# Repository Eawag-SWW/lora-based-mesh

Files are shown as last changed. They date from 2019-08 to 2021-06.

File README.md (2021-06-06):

# LPWAN for sewer monitoring - A synchronous LoRa-based mesh data communication protocol
Documentation, firmware and hardware specification | Cooperative development: InES, ZHAW Winterthur & Eawag, Dübendorf (Switzerland) 

## Graphical Abstract

EBI_etal_graphical_abstract_xs

## Synopsis
Although emerging low-power wireless communication techniques allow efficient data transfers with great above-ground performance, for underground or indoor applications a large coverage range is difficult to achieve due to physical and topological limitations. This repository provides detailed information on a novel LPWAN concept that i) enhances transmission reliability, efficiency and flexibility in range-critical situations through meshed multi-hop routing, and ii) ensures a precise time-synchronization through optional GPS or DCF77 long-wave time signaling.

## Project-related Open Access Publication
https://ieeexplore.ieee.org/document/8703036

## Hardware Specification
Find i) the assembly of the material used, ii) the drawings for sensor node chassis, and iii) PCB related material [here](./Hardware).
## Software Code
Concept-specific firmware is provided [here](./Software).
## Miscellaneous
Institutional project website -> www.eawag.ch/sewerlpwan

Related project(s): 
Urban Water Observatory -> www.eawag.ch/uwo

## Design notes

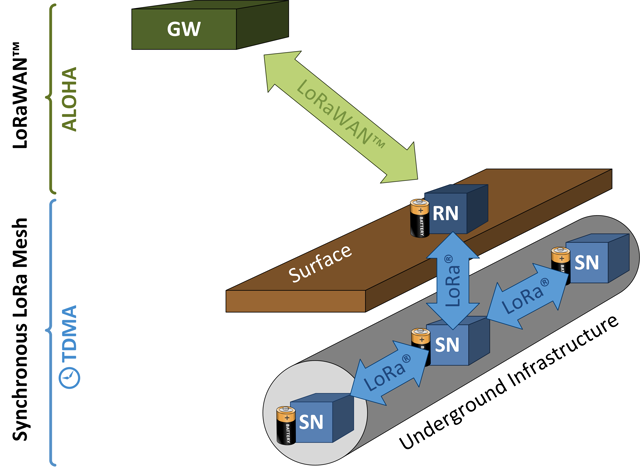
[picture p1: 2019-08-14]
EBI_etal_graphical_abstract_s.png

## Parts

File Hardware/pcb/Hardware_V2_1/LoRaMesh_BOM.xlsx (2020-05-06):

Designator | Comment | Description | Footprint | LibRef | Quantity | Manufacturer | Manufacturer Part Number | Distributor | Distributor Part Number | Value
A2, A3 | Ant Chip |  | ANT_CHIP_868_woC | Ant_Chip_868_woC | 2 |  |  | Digikey | 931-1082-2-ND | ILA.02
C1, C2, C58, C59, C60, C76, C80, C81 | 100uF | Capacitor SMD | rlc_805_smd | Cap | 8 |  |  |  |  | 100uF
C3, C4, C5, C6, C14, C15, C21, C23, C24, C28, C42, C57, C67, C71, C72, C73, C78, C79, C82 | 100nF | Capacitor SMD | rlc_402_smd | Cap | 19 |  |  |  |  | 100nF
C7, C8, C18, C19, C20, C26, C36, C38, C39 | 47pF | Capacitor SMD | rlc_402_smd | Cap | 9 |  |  |  |  | 47pF
C9 | 33pF | Capacitor SMD | rlc_402_smd | Cap | 1 |  |  |  |  | 33pF
C10 | 1.5pF | Capacitor SMD | rlc_402_smd | Cap | 1 |  |  |  |  | 1.5pF
C11, C29, C50 | 4.7pF | Capacitor SMD | rlc_402_smd | Cap | 3 |  |  |  |  | 4.7pF
C12 | 1.2pF | Capacitor SMD | rlc_402_smd | Cap | 1 |  |  |  |  | 1.2pF
C13 | 1.8pF | Capacitor SMD | rlc_402_smd | Cap | 1 |  |  |  |  | 1.8pF
C16, C33, C34, C37, C40, C41, C46, C47, C51, C83, C101, R15, R46 | NC | Capacitor SMD, Capacitor SMD, Capacitor SMD, Capacitor SMD, Capacitor SMD, Capacitor SMD, Capacitor SMD, Capacitor SMD, Capacitor, Capacitor SMD, Capacitor, Resistor SMD - IEC symbol version, Resistor SMD - IEC symbol version | rlc_402_smd | Cap, Cap, Cap, Cap, Cap, Cap, Cap, Cap, C, Cap, C, Resistor, Resistor | 13 |  |  |  |  | NC
C17 | 3.3pF | Capacitor SMD | rlc_402_smd | Cap | 1 |  |  |  |  | 3.3pF
C22, C25, C43, C45 | 1nF | Capacitor SMD | rlc_402_smd | Cap | 4 |  |  |  |  | 1nF
C27, C44, C56, C66, C70, C75 | 1uF | Capacitor SMD | rlc_402_smd | Cap | 6 |  |  |  |  | 1uF
C30, C32 | 6.8pF | Capacitor SMD | rlc_402_smd | Cap | 2 |  |  |  |  | 6.8pF
C31 | 2.7pF | Capacitor SMD | rlc_402_smd | Cap | 1 |  |  |  |  | 2.7pF
C35 | 10nF | Capacitor SMD | rlc_402_smd | Cap | 1 |  |  |  |  | 10nF
C48, C49, C87, C88 | 15pF | Capacitor SMD | rlc_402_smd | Cap | 4 |  |  |  |  | 15pF
C52, C53, C54, C74, C98, C99, C100 | 10uF | Capacitor SMD | rlc_603_smd | Cap | 7 |  |  |  |  | 10uF
C68, C69 | 18pF | Capacitor SMD | rlc_402_smd | Cap | 2 |  |  |  |  | 18pF
C77 | NC | Capacitor SMD | rlc_603_smd | Cap | 1 |  |  |  |  | NC
D1 | BAT60JFILM | BAT60JFILM | SOD323/A | BAT60JFILM | 1 | STMicroelectronics | BAT60JFILM | Digikey | 497-3707-1-ND | BAT60JFILM
D2 | LED_ORANGE | LED ORANGE CLEAR 0603 SMD | CD1608-0603 | LED_ORANGE | 1 | Lite-On Inc. | LTST-C191KFKT | digikey |  | LTST-C191KFKT
D3 | LED_GREEN | LED GREEN CLEAR 0603 SMD | CD1608-0603 | LED_GREEN | 1 | Lite-On Inc. | LTST-C191KGKT | digikey |  | LTST-C191KGKT
J1, J2, J4 | 0R | Switching Path between two different with a Resistor | 0402 3-Way | 3 Way Resistor Switch | 3 |  |  |  |  | 0R
J10 | DM3AT-SF-PEJM5 | DM3 Series 8 Position Right Angle SMT Push Push Ejection MicroSD Card Connector | DM3AT-SF-PEJM5_DM3AT-SF-PEJM5(Primary) | DM3AT-SF-PEJM5 | 1 | Hirose Electric Co Ltd | DM3AT-SF-PEJM5 | Digikey | HR1964TR-ND | DM3AT-SF-PEJM5
JP1 | Jumper 3-Pol | Jumper 3 Pol | JMP 1X3 | Jumper 3-Pol | 1
JP2 | Jumper | Jumper Wire | bridge_254mm | Jumper | 1 |  |  |  |  | NC
L1 | 82nH | Inductor SMD | rlc_402_smd | Inductor | 1 | Murata | LQG15HS82NJ02D | Digikey | 490-2634-1-ND | 82nH
L2 | 33nH | Inductor SMD | rlc_402_smd | Inductor | 1 | Murata | LQW15AN33NJ00D | Digikey | 490-1152-1-ND | 33nH
L3, L20 | 2.2u | Inductor | rlc_1008_smd | Inductor | 2 | Murata | DFE252012P-2R2M=P2 | Digikey | 490-10649-1-ND | 2.2u
L4, L7 | 10nH | Inductor SMD | rlc_402_smd | Inductor | 2 | Murata | LQG15HS10NJ02D | Digikey | 490-2623-1-ND | 10nH
L5 | 6.2nH | Inductor SMD | rlc_402_smd | Inductor | 1 | Murata | LQG15HS6N2S02D | Digikey | 490-2620-1-ND | 6.2nH
L6 | 15nH | Inductor SMD | rlc_402_smd | Inductor | 1 | Murata | LQG15HS15NJ02D | Digikey | 490-2625-1-ND | 15nH
L8, L10, L11, L14, R16, R40, R45, R47, R66, R67, R68, R69 | 0R | Inductor SMD, Inductor SMD, Inductor SMD, Inductor SMD, Resistor SMD - IEC symbol version, Resistor SMD - IEC symbol version, Resistor SMD - IEC symbol version, Resistor SMD - IEC symbol version, Resistor SMD - IEC symbol version, Resistor SMD - IEC symbol version, Resistor SMD - IEC symbol version, Resistor SMD - IEC symbol version | rlc_402_smd | Inductor, Inductor, Inductor, Inductor, Resistor, Resistor, Resistor, Resistor, Resistor, Resistor, Resistor, Resistor | 12 |  |  |  |  | 0R
L9 | 12nH | Inductor SMD | rlc_402_smd | Inductor | 1 | Murata | LQG15HS12NJ02D | Digikey | 490-2624-1-ND | 12nH
L12, L16 | (L) LPS3015 | Coilcraft LPS3015 3mm x 3mm | LPS3015 L 3 x 3 | (L) LPS3015 | 2 | Coilcraft | LPS3015-152MRB | Mouser | 994-LPS3015-152MRB | 1.5uH 1.7A 20%
L13 | 18nH | Inductor SMD | rlc_402_smd | Inductor | 1 | LQG15HS18NJ02D | Murata | Digikey | 490-2626-1-ND | 18nH
L17 | 100uH | Inductor | 0603L | Inductor | 1 |  |  |  |  | 100uH
P1 | Header 3X2 | Header, 3-Pin, Dual row | HDR2X3 | Header 3X2 | 1 | Amphenol ICC (FCI) | 67997-206HLF | Digikey | 609-3234-ND
P2 | Header 4 | Header, 4-Pin | HDR1X4 | Header 4 | 1 | TE Connectivity AMP Connectors | 640456-4 | Digikey | A1922-ND
P3 | NC | Header, 3-Pin | HDR1X3 | Header 3 | 1 |  |  |  |  | NC
P4 | Header 3 | Header, 3-Pin | HDR1X3 | Header 3 | 1
P5 | SM12xx 10x2 header | SM12xx Header | HDR20_SX12xx | SM12xx only 10x2 Header | 1
P7 | Header 6X1 | Header, 6-Pin, Single row | 1*6P | Header 6X1 | 1
P8 | B2B-PH-K-S | 2 Pin, Through-hole type shrouded header | B2B-PH-K-S | B2B-PH-K-S | 1 | JST Sales America Inc. | B2B-PH-K-S(LF)(SN) | Digikey | 455-1704-ND | B2B-PH-K-S
Q2 | IRLML6302 | P-Channel SIPMOS Small-Signal-Transistor, -60 V VDS, -0.62 A ID, -55 to 150 degC, PG-SC59, Reel, Green | INF-PG-SC59_N | BSR315P | 1 | Infineon |  |  |  | IRLML6302
Q3 | BSS670S2L | N-Channel OptiMOS Buck Converter Series, 55 V VDS, 0.54 A ID, -55 to 150 degC, PG-SOT23, Reel, Green | INF-PG-SOT23_N | BSS670S2L | 1 | Infineon |  |  |  | BSS670S2L
R1, R4, R11, R18, R19, R24, R26, R43, R49 | 0R | Resistor | CHIP 0402 | R | 9 |  |  |  |  | 0R
R2, R6, R20, R27, R44 | 3.3M | Resistor | CHIP 0402 | R | 5 |  |  |  |  | 3.3M
R3, R48 | 5pF | Resistor | CHIP 0402 | R | 2 |  |  |  |  | 5pF
R5, R8, R13, R23, R25, R28, R35, R37, R39, R41, R50, R51, R52, R54, R63, R64, R65, R70 | NC | Resistor | CHIP 0402 | R | 18 |  |  |  |  | NC
R7 | 100 | Resistor SMD - IEC symbol version | rlc_402_smd | Resistor | 1 |  |  |  |  | 100
R9, R79 | 1M / 1% | Resistor | CHIP 0402 | R | 2 |  |  |  |  | 1M / 1%
R10, R80 | 430k / 1% | Resistor | CHIP 0402 | R | 2 |  |  |  |  | 430k / 1%
R12 | 1k | Resistor SMD - IEC symbol version | rlc_402_smd | Resistor | 1 |  |  |  |  | 1k
R14, R17 | 130 | Resistor | CHIP 0402 | R | 2 |  |  |  |  | 130
R29 | 100 | Resistor | CHIP 0402 | R | 1 |  |  |  |  | 100
R30 | 4k7 | Resistor | CHIP 0402 | R | 1 |  |  |  |  | 4k7
R31, R33, R42 | 10k | Resistor, Resistor, Resistor 0402 / 0603 / 0805 | CHIP 0402 | R, R, Resistor_ST | 3 |  |  |  |  | 10k
R32, R34, R36, R38 | 22 | Resistor | CHIP 0402 | R | 4 |  |  |  |  | 22
R55 | 120R | Resistor SMD - IEC symbol version | rlc_1206_smd | Resistor | 1 |  |  |  |  | 120R
R56, R59, R60, R61, R62 | 100k | Resistor | CHIP 0402 | R | 5 |  |  |  |  | 100k
R57 | 270k | Resistor | CHIP 0402 | R | 1 |  |  |  |  | 270k
R58 | 560k | Resistor | CHIP 0402 | R | 1 |  |  |  |  | 560k
RXTX_RFMOD | Test Pin | Test Pin | pin_SMD | test_pin | 1 |  |  |  |  | NC
SW1, SW2 | EVP-AWBA2A | Tactile Switch SPST-NO Top Actuated Surface Mount | PB_EVP-AWBA2A | EVP-AWBA2A | 2 | Panasonic Electronic Components | EVP-AWBA2A | Digikey | P16850CT-ND | EVP-AWBA2A
T1, T3, T4, T5 | DMG2301LK-7 | MOS FET P-Channel | SOT-23 | DMG2301L | 4 | Diodes Incorporated | DMG2301LK-7 | Digikey | DMG2301LK-7DITR-ND | DMG2301LK-7
T2 | DMG2301LK-7 | MOS FET P-Channel | SOT-23 | DMG2301L | 1 | Diodes Incorporated | DMG2301LK-7 | Digikey | DMG2301LK-7DITR-ND | DMG2301LK-7
U1 | SX1276 | SX1276 - Low Power Integrated UHF Transceiver with loRa Modem | vqfn28_6x6mm | SX1276 | 1 | Semtech | SX1276IMLTRT | Digikey | SX1276IMLTRTCT-ND | SX1276
U2, U5 | RF Switch | PE4259 Peregrine RF Switch | SC70-6 | PE4259 RF Switch | 2 | pSemi | PE4259 | Digikey | 1046-1011-1-ND | PE4259
U3 | WiMOD iM880B-L LoRaWAN |  | WiMOD iM880A | WiMOD iM880B | 1 | IMST | iM880B-L LoRaWAN | https://shop.imst.de | 404791 | WiMOD iM880B-L LoRaWAN
U4, U17 | TPS61099 | Boost Converter with Ultra-Low Quiescent Current | YFF0006 | TPS61099 | 2 | Texas Intruments | TPS61099 |  |  | TPS61099
U6 | DS32KHZ |  | SO-16 | TCXO_32kHz | 1 | Maxim Integrated | DS32KHZSN#T&R | Digikey | DS32KHZSN#CT-ND | DS32KHZ
U7 | NC7SZ04 |  | SOT23-5 | NC7SZ04 | 1 | Fairchild/ON Semiconductor | NC7SZ04P5X | Digikey | NC7SZ04M5CT-ND | NC7SZ04
U9 | MCU_LQFP64 |  | LQFP64 | MCU_LQFP64 | 1 | STMicroelectronics | STM32L476RGT6 | Digikey | 497-15877-ND | STM32L476RGT6
U10 | MAX3483ESA+ | IC TXRX RS485/422 250KBPS 8-SOIC | SOP8_MAX348x | MAX3483ESA+ | 1 | Maxim Integrated |  | Digikey | MAX3483ESA+-ND | MAX3483ESA+
U11 | ADM3222ARUZ | IC TX/RX RS232 3.3V W/SD 20TSSOP | SOP20_ADM3222 | ADM3222 | 1 | Analog Devices Inc. | ADM3222ARUZ | Digikey | ADM3222ARUZ-ND | ADM3222ARUZ
U12, U13, U14 | SN74LVC1G125 |  | SOT23-5 | SN74LVC1G125 | 3 | Texas Instruments | SN74LVC1G125DBVR | Digikey | 296-11603-1-ND | SN74LVC1G125
X1, X5 | UFL Connector | U.FL SMT Connector Male | U.FL | UF.L Sockel | 2 | Hirose Electric Co Ltd | CONN U.FL RCPT STR 50 OHM SMD, U.FL-R-SMT-1(10) | Digikey | H11891CT-ND | H11891CT-ND
X2 | NC | Connector 10 Pol | HEADER 2X5 50mil | CON 2x5 | 1 |  |  |  |  | NC
X3 | HEADER | Connector 6Pol | HEADER 2x3 100mil | CON 2x3 | 1 | Amphenol ICC (FCI) | 67997-206HLF | Digikey | 609-3234-ND | 67997-206HLF
X4, X8 | SMA | SMA Connector Straight, Molex LLC 0732511352 | SMA_Jack_STR_50Ohm | SMA | 2 | Molex | 0732511352 | Digikey | WM9458-ND | 0732511352
X6, X7 | 8x Connector cage clamp |  | 8xClamp Connector 2.54mm | 8x Connector cage clamp | 2 | WAGO | 234-508. | Farnell | 1777107 | 234-508.
Y1 | 8 MHz / 16pF | Crystal | XTAL1 | CRYSTAL | 1 | IQD | LFXTAL029665Reel | Mouser | 449-LFXTAL029665REEL | 8 MHz / 16pF
Y2 | 32 MHz / 10pF |  | 5.0x3.2MM TXC 7B-32 | Quartz Crystal | 1 | TXC CORPORATION | 7B-32.000MEEQ-T | Digikey | 887-1312-1-ND | 32 MHz / 10pF

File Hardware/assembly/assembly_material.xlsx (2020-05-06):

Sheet: All
LoRaMesh Baugruppen Komponenten
 | Bezeichnung | Hersteller | Herstellerbezeichnung | Lieferant | Teilenummer | Stückkosten | Bedarf | Bestellmenge | Eawag Lager | Bestellwert
 | SN Gehäuse Standard | Bopla | ET 215 | Distrelec | 150-61-867 | 12.88 | 15 | 15 |  | 193.2
 | SN Gehäuse Ex | ROSE | 05 081306 | www.phoenix-mecano.ch | 05 081306 | 62.08 | 8 | 0 | 8 | 0
 | RN Gehäuse | Bopla | M 227 | Distrelec | 150-61-765 | 29.72 | 15 | 15 |  | 445.8
 | Trägerplatte M227 | Qualicut AG |  | Qualicut AG |  | 20 | 10 | 10 |  | 200
 | Trägerplatte ROSE | Qualicut AG |  | Qualicut AG |  | 20 | 10 | 10 |  | 200
 | Batteriehalter | MPD | BH2CL | Digi-Key | BH2CL-ND | 1.81 | 30 | 25 | 6 | 45.25
 | Antennen 0dB für Kunsstoffghäuse | LINX | ANT-868-CW-HW-SMA | Digi-Key | ANT-868-CW-HW-SMA-ND | 8.08 | 32 | 30 | 5 | 242.4
 | Antennen 2dB für Metallgehäuse | Nearson | S463AM-868 | Digi-Key | 730-1064-ND | 17.93 | 8 | 5 | 5 | 89.65
 | Antennenkabel | MULTICOMP | MC000821 | Farnell | 2452717 | 6.97 | 50 | 50 |  | 348.5
 | Druckausgleichselement Standard | W.L. Gore | PMF10032I GREY | Distrelec | 150-15-938 | 6.95 | 22 | 25 |  | 173.75
 | Druckausgleichselement Ex | AGRO | EX2450.12.34 | AGRO | EX2450.12.34 | 15.7 | 8 | 0 | 9 | 0
 | Verschraubung Standard | Hummel | Typ LCM 12 G | Distrelec | 155-01-218 | 0.59 | 22 | 30 |  | 17.7
 | O-Ring | Hummel | 1.321.1200.57 | Distrelec | 155-12-371 | 0.3 | 22 | 30 |  | 9
 | Verschraubung Ex | Lapp | SKINTOP K-M 12X2,5 | Distrelec | 300-20-170 | 2.85 | 20 | 0 | 13 | 0
 | GPS Receiver | Adafruit | Adafruit Ultimate GPS | Play-Zone | 746 | 44.9 | 5 | 5 |  | 224.5
 | DCF77 Module | HKW Elektronik | FUM DCF | HKW Elektronik | FMD01021R | 20 | 10 | 15 |  | 300
 | DCF77 Antennen | HKW Elektronik | AFeT 77,5 - 10x60/70 | HKW Elektronik | FTD02012R | 3.8 | 10 | 15 |  | 57
 | Batterien C/LR14 | Duracell | ID1400 10P | Distrelec | 110-95-837 | 1.31 | 60 | 60 |  | 78.6
 | microSD Karte | Kingston | SDCIT/8GBSP | Distrelec | 300-75-066 | 12.9 | 25 | 30 |  | 387
 | Montagematerial Schrauben
 |  |  |  |  |  |  |  |  |  | 3012.35

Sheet: Repeater Node GPS
LoRaMesh Baugruppen Komponenten
 | Bezeichnung | Hersteller | Herstellerbezeichnung | Lieferant | Teilenummer | Stückkosten
 | SN Gehäuse Standard | Bopla | ET 215 | Distrelec | 150-61-867 | 12.88 | 0
 | SN Gehäuse Ex | ROSE | 05 081306 | www.phoenix-mecano.ch | 05 081306 | 62.08 | 0
1 | RN Gehäuse | Bopla | M 227 | Distrelec | 150-61-765 | 29.72 | 29.72
1 | Trägerplatte M227 | Qualicut AG |  | Qualicut AG |  | 20 | 20
 | Trägerplatte ROSE | Qualicut AG |  | Qualicut AG |  | 20 | 0
1 | Batteriehalter | MPD | BH2CL | Digi-Key | BH2CL-ND | 1.81 | 1.81
2 | Antennen 0dB für Kunsstoffghäuse | LINX | ANT-868-CW-HW-SMA | Digi-Key | ANT-868-CW-HW-SMA-ND | 8.08 | 16.16
 | Antennen 2dB für Metallgehäuse | Nearson | S463AM-868 | Digi-Key | 730-1064-ND | 17.93 | 0
2 | Antennenkabel | MULTICOMP | MC000821 | Farnell | 2452717 | 6.97 | 13.94
1 | Druckausgleichselement Standard | W.L. Gore | PMF10032I GREY | Distrelec | 150-15-938 | 6.95 | 6.95
 | Druckausgleichselement Ex | AGRO | EX2450.12.34 | AGRO | EX2450.12.34 | 15.7 | 0
 | Verschraubung Standard | Hummel | Typ LCM 12 G | Distrelec | 155-01-218 | 0.59 | 0
 | O-Ring | Hummel | 1.321.1200.57 | Distrelec | 155-12-371 | 0.3 | 0
 | Verschraubung Ex | Lapp | SKINTOP K-M 12X2,5 | Distrelec | 300-20-170 | 2.85 | 0
1 | GPS Receiver | Adafruit | Adafruit Ultimate GPS | Play-Zone | 746 | 44.9 | 44.9
 | DCF77 Module | HKW Elektronik | FUM DCF | HKW Elektronik | FMD01021R | 20 | 0
 | DCF77 Antennen | HKW Elektronik | AFeT 77,5 - 10x60/70 | HKW Elektronik | FTD02012R | 3.8 | 0
2 | Batterien C/LR14 | Duracell | ID1400 10P | Distrelec | 110-95-837 | 1.31 | 2.62
1 | microSD Karte | Kingston | SDCIT/8GBSP | Distrelec | 300-75-066 | 12.9 | 12.9
1 | Montagematerial pauschal |  |  |  |  | 1 | 1
 | Total |  |  |  |  |  | 149

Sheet: Repeater Node DCF77
LoRaMesh Baugruppen Komponenten
 | Bezeichnung | Hersteller | Herstellerbezeichnung | Lieferant | Teilenummer | Stückkosten
 | SN Gehäuse Standard | Bopla | ET 215 | Distrelec | 150-61-867 | 12.88 | 0
 | SN Gehäuse Ex | ROSE | 05 081306 | www.phoenix-mecano.ch | 05 081306 | 62.08 | 0
1 | RN Gehäuse | Bopla | M 227 | Distrelec | 150-61-765 | 29.72 | 29.72
1 | Trägerplatte M227 | Qualicut AG |  | Qualicut AG |  | 20 | 20
 | Trägerplatte ROSE | Qualicut AG |  | Qualicut AG |  | 20 | 0
1 | Batteriehalter | MPD | BH2CL | Digi-Key | BH2CL-ND | 1.81 | 1.81
2 | Antennen 0dB für Kunsstoffghäuse | LINX | ANT-868-CW-HW-SMA | Digi-Key | ANT-868-CW-HW-SMA-ND | 8.08 | 16.16
 | Antennen 2dB für Metallgehäuse | Nearson | S463AM-868 | Digi-Key | 730-1064-ND | 17.93 | 0
2 | Antennenkabel | MULTICOMP | MC000821 | Farnell | 2452717 | 6.97 | 13.94
1 | Druckausgleichselement Standard | W.L. Gore | PMF10032I GREY | Distrelec | 150-15-938 | 6.95 | 6.95
 | Druckausgleichselement Ex | AGRO | EX2450.12.34 | AGRO | EX2450.12.34 | 15.7 | 0
 | Verschraubung Standard | Hummel | Typ LCM 12 G | Distrelec | 155-01-218 | 0.59 | 0
 | O-Ring | Hummel | 1.321.1200.57 | Distrelec | 155-12-371 | 0.3 | 0
 | Verschraubung Ex | Lapp | SKINTOP K-M 12X2,5 | Distrelec | 300-20-170 | 2.85 | 0
 | GPS Receiver | Adafruit | Adafruit Ultimate GPS | Play-Zone | 746 | 44.9 | 0
1 | DCF77 Module | HKW Elektronik | FUM DCF | HKW Elektronik | FMD01021R | 20 | 20
1 | DCF77 Antennen | HKW Elektronik | AFeT 77,5 - 10x60/70 | HKW Elektronik | FTD02012R | 3.8 | 3.8
2 | Batterien C/LR14 | Duracell | ID1400 10P | Distrelec | 110-95-837 | 1.31 | 2.62
1 | microSD Karte | Kingston | SDCIT/8GBSP | Distrelec | 300-75-066 | 12.9 | 12.9
1 | Montagematerial pauschal |  |  |  |  | 1 | 1
 | Total |  |  |  |  |  | 127.9

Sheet: Sensor Node Ex
LoRaMesh Baugruppen Komponenten
 | Bezeichnung | Hersteller | Herstellerbezeichnung | Lieferant | Teilenummer | Stückkosten
 | SN Gehäuse Standard | Bopla | ET 215 | Distrelec | 150-61-867 | 12.88 | 0
1 | SN Gehäuse Ex | ROSE | 05 081306 | www.phoenix-mecano.ch | 05 081306 | 62.08 | 62.08
 | RN Gehäuse | Bopla | M 227 | Distrelec | 150-61-765 | 29.72 | 0
 | Trägerplatte M227 | Qualicut AG |  | Qualicut AG |  | 20 | 0
1 | Trägerplatte ROSE | Qualicut AG |  | Qualicut AG |  | 20 | 20
1 | Batteriehalter | MPD | BH2CL | Digi-Key | BH2CL-ND | 1.81 | 1.81
 | Antennen 0dB für Kunsstoffghäuse | LINX | ANT-868-CW-HW-SMA | Digi-Key | ANT-868-CW-HW-SMA-ND | 8.08 | 0
1 | Antennen 2dB für Metallgehäuse | Nearson | S463AM-868 | Digi-Key | 730-1064-ND | 17.93 | 17.93
1 | Antennenkabel | MULTICOMP | MC000821 | Farnell | 2452717 | 6.97 | 6.97
 | Druckausgleichselement Standard | W.L. Gore | PMF10032I GREY | Distrelec | 150-15-938 | 6.95 | 0
1 | Druckausgleichselement Ex | AGRO | EX2450.12.34 | AGRO | EX2450.12.34 | 15.7 | 15.7
 | Verschraubung Standard | Hummel | Typ LCM 12 G | Distrelec | 155-01-218 | 0.59 | 0
 | O-Ring | Hummel | 1.321.1200.57 | Distrelec | 155-12-371 | 0.3 | 0
1 | Verschraubung Ex | Lapp | SKINTOP K-M 12X2,5 | Distrelec | 300-20-170 | 2.85 | 2.85
 | GPS Receiver | Adafruit | Adafruit Ultimate GPS | Play-Zone | 746 | 44.9 | 0
 | DCF77 Module | HKW Elektronik | FUM DCF | HKW Elektronik | FMD01021R | 20 | 0
 | DCF77 Antennen | HKW Elektronik | AFeT 77,5 - 10x60/70 | HKW Elektronik | FTD02012R | 3.8 | 0
2 | Batterien C/LR14 | Duracell | ID1400 10P | Distrelec | 110-95-837 | 1.31 | 2.62
1 | microSD Karte | Kingston | SDCIT/8GBSP | Distrelec | 300-75-066 | 12.9 | 12.9
1 | Montagematerial pauschal |  |  |  |  | 1 | 1
 | Total |  |  |  |  |  | 142.86

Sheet: Sensor Node Standard
LoRaMesh Baugruppen Komponenten
 | Bezeichnung | Hersteller | Herstellerbezeichnung | Lieferant | Teilenummer | Stückkosten
1 | SN Gehäuse Standard | Bopla | ET 215 | Distrelec | 150-61-867 | 12.88 | 12.88
 | SN Gehäuse Ex | ROSE | 05 081306 | www.phoenix-mecano.ch | 05 081306 | 62.08 | 0
 | RN Gehäuse | Bopla | M 227 | Distrelec | 150-61-765 | 29.72 | 0
 | Trägerplatte M227 | Qualicut AG |  | Qualicut AG |  | 20 | 0
 | Trägerplatte ROSE | Qualicut AG |  | Qualicut AG |  | 20 | 0
1 | Batteriehalter | MPD | BH2CL | Digi-Key | BH2CL-ND | 1.81 | 1.81
1 | Antennen 0dB für Kunsstoffghäuse | LINX | ANT-868-CW-HW-SMA | Digi-Key | ANT-868-CW-HW-SMA-ND | 8.08 | 8.08
 | Antennen 2dB für Metallgehäuse | Nearson | S463AM-868 | Digi-Key | 730-1064-ND | 17.93 | 0
1 | Antennenkabel | MULTICOMP | MC000821 | Farnell | 2452717 | 6.97 | 6.97
1 | Druckausgleichselement Standard | W.L. Gore | PMF10032I GREY | Distrelec | 150-15-938 | 6.95 | 6.95
 | Druckausgleichselement Ex | AGRO | EX2450.12.34 | AGRO | EX2450.12.34 | 15.7 | 0
1 | Verschraubung Standard | Hummel | Typ LCM 12 G | Distrelec | 155-01-218 | 0.59 | 0.59
1 | O-Ring | Hummel | 1.321.1200.57 | Distrelec | 155-12-371 | 0.3 | 0.3
 | Verschraubung Ex | Lapp | SKINTOP K-M 12X2,5 | Distrelec | 300-20-170 | 2.85 | 0
 | GPS Receiver | Adafruit | Adafruit Ultimate GPS | Play-Zone | 746 | 44.9 | 0
 | DCF77 Module | HKW Elektronik | FUM DCF | HKW Elektronik | FMD01021R | 20 | 0
 | DCF77 Antennen | HKW Elektronik | AFeT 77,5 - 10x60/70 | HKW Elektronik | FTD02012R | 3.8 | 0
2 | Batterien C/LR14 | Duracell | ID1400 10P | Distrelec | 110-95-837 | 1.31 | 2.62
1 | microSD Karte | Kingston | SDCIT/8GBSP | Distrelec | 300-75-066 | 12.9 | 12.9
1 | Montagematerial pauschal |  |  |  |  | 1 | 1
 | Total |  |  |  |  |  | 53.1

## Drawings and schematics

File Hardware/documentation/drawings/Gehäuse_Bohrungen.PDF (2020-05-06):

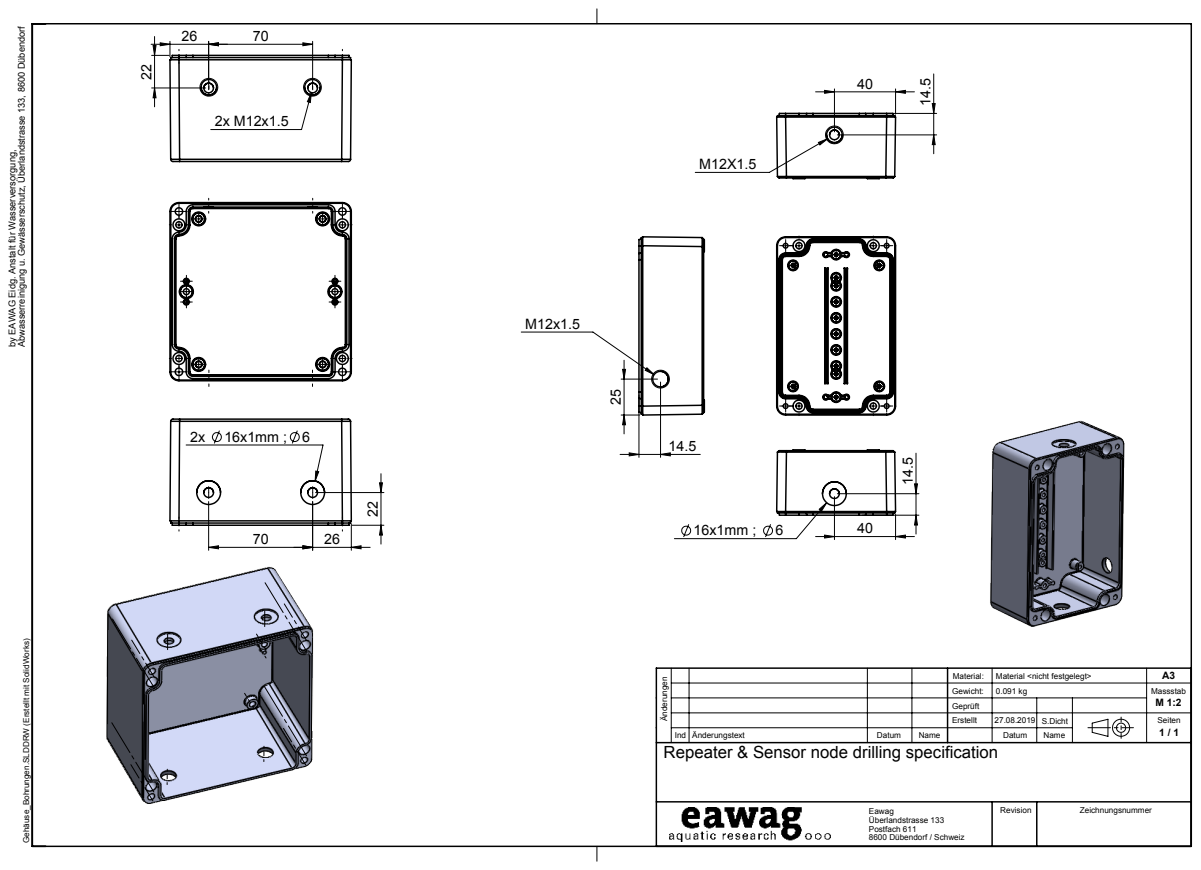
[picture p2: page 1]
Erstellt; 27.08.2019 S.Dicht; Ind Änderungstext; Datum; Name; Überlandstrasse 133 Postfach 611 8600 Dübendorf / Schweiz

by EAWAG Eidg. Anstalt für Wasserversorgung, Abwasserreinigung u. Gewässerschutz, Überlandstrasse 133, 8600 Dübendorf Gehäuse_Bohrungen.SLDDRW (Erstellt mit SolidWorks)

Material <nicht festgelegt>

Repeater & Sensor node drilling specification

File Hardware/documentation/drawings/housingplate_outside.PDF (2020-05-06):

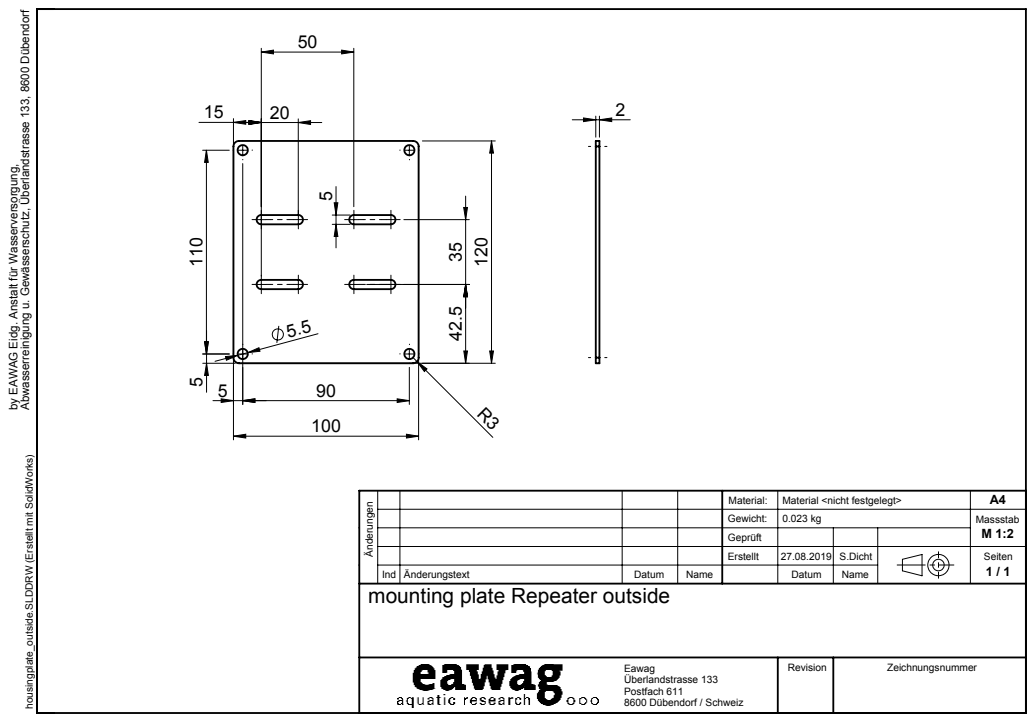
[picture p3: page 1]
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

by EAWAG Eidg. Anstalt für Wasserversorgung, Abwasserreinigung u. Gewässerschutz, Überlandstrasse 133, 8600 Dübendorf housingplate_outside.SLDDRW (Erstellt mit SolidWorks)

Material <nicht festgelegt>

mounting plate Repeater outside

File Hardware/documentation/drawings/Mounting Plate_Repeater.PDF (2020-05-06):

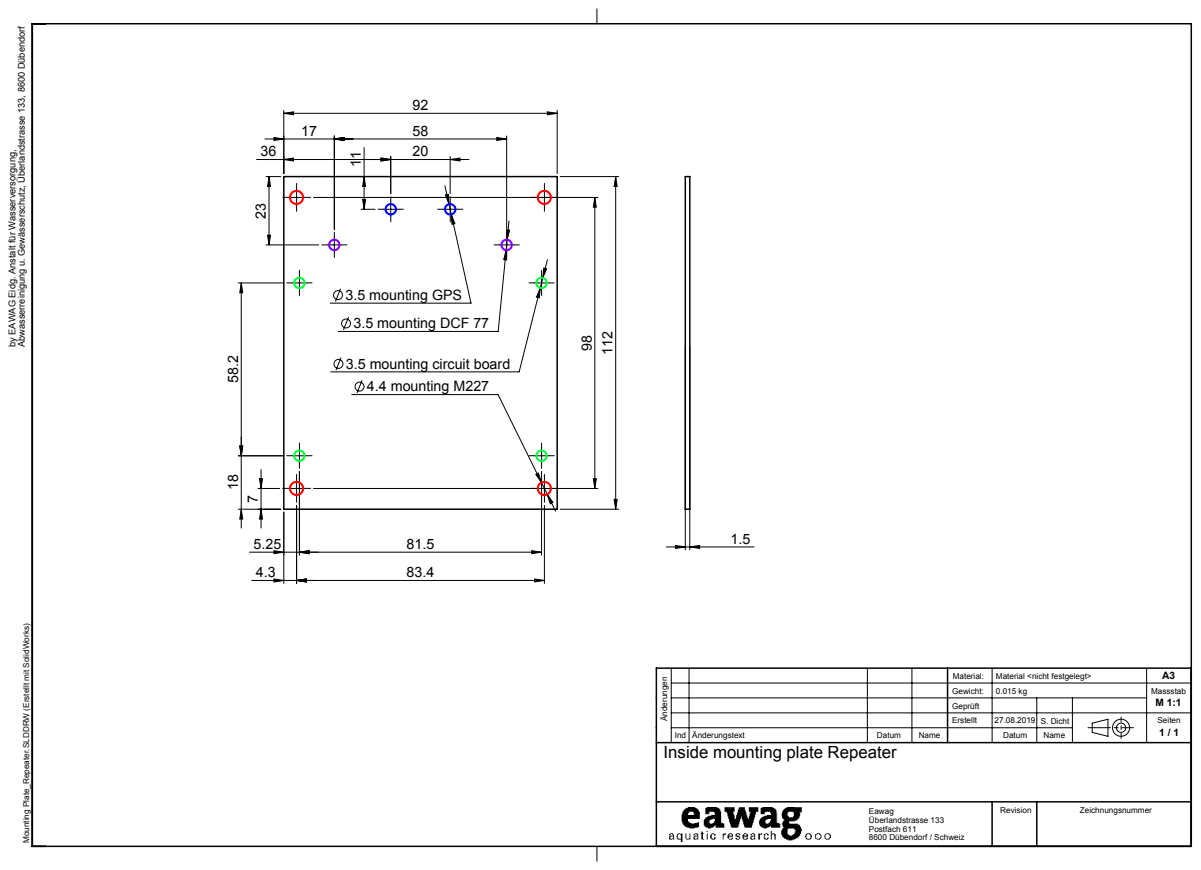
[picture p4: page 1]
3.5 mounting DCF 77; 3.5 mounting GPS; Erstellt; 27.08.2019 S. Dicht; Ind Änderungstext; Datum; Name; Überlandstrasse 133 Postfach 611 8600 Dübendorf / Schweiz

by EAWAG Eidg. Anstalt für Wasserversorgung, Abwasserreinigung u. Gewässerschutz, Überlandstrasse 133, 8600 Dübendorf Mounting Plate_Repeater.SLDDRW (Erstellt mit SolidWorks)

3.5 mounting circuit board
4.4 mounting M227

Material <nicht festgelegt>

Inside mounting plate Repeater

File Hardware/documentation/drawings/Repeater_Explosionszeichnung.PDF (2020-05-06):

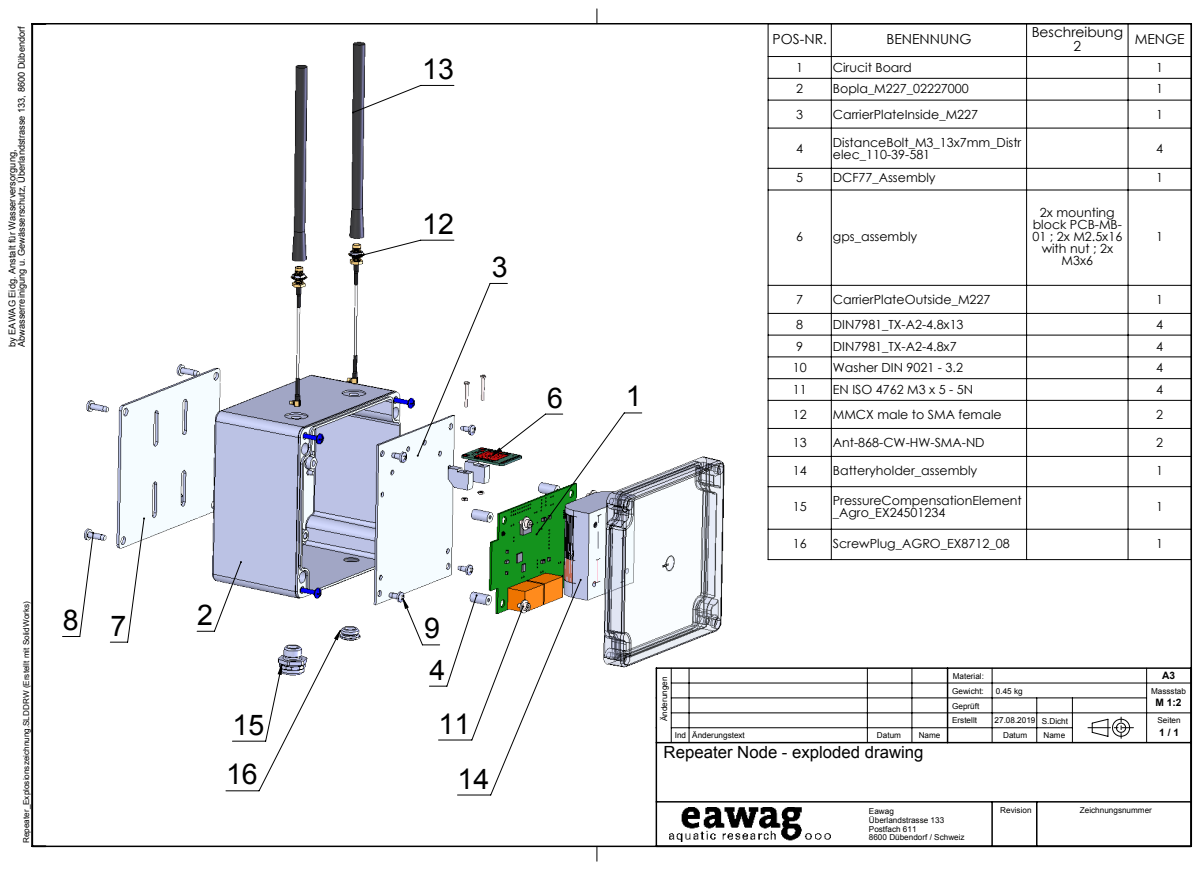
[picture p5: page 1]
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

POS-NR. | Cirucit Board CarrierPlateInside_M227 DistanceBolt_M3_13x7mm_Distr Bopla_M227_02227000 BENENNUNG | Beschreibung 2 | MENGE 1 1 2 1 3 1 4

by EAWAG Eidg. Anstalt für Wasserversorgung, Abwasserreinigung u. Gewässerschutz, Überlandstrasse 133, 8600 Dübendorf Repeater_Explosionszeichnung.SLDDRW (Erstellt mit SolidWorks)

elec_110-39-581 | | 4
5 | DCF77_Assembly | | 1

6 | gps_assembly | 2x mounting block PCB-MB-01 ; 2x M2.5x16 with nut ; 2x M3x6 | 1

7 | CarrierPlateOutside_M227 | | 1
8 | DIN7981_TX-A2-4.8x13 | | 4
9 | DIN7981_TX-A2-4.8x7 | | 4
10 | Washer DIN 9021 - 3.2 | | 4
11 | EN ISO 4762 M3 x 5 - 5N | | 4
12 | MMCX male to SMA female | | 2
13 | Ant-868-CW-HW-SMA-ND | | 2
14 | Batteryholder_assembly | | 1
15 | PressureCompensationElement _Agro_EX24501234 | | 1

16 | ScrewPlug_AGRO_EX8712_08 | | 1

Repeater Node - exploded drawing

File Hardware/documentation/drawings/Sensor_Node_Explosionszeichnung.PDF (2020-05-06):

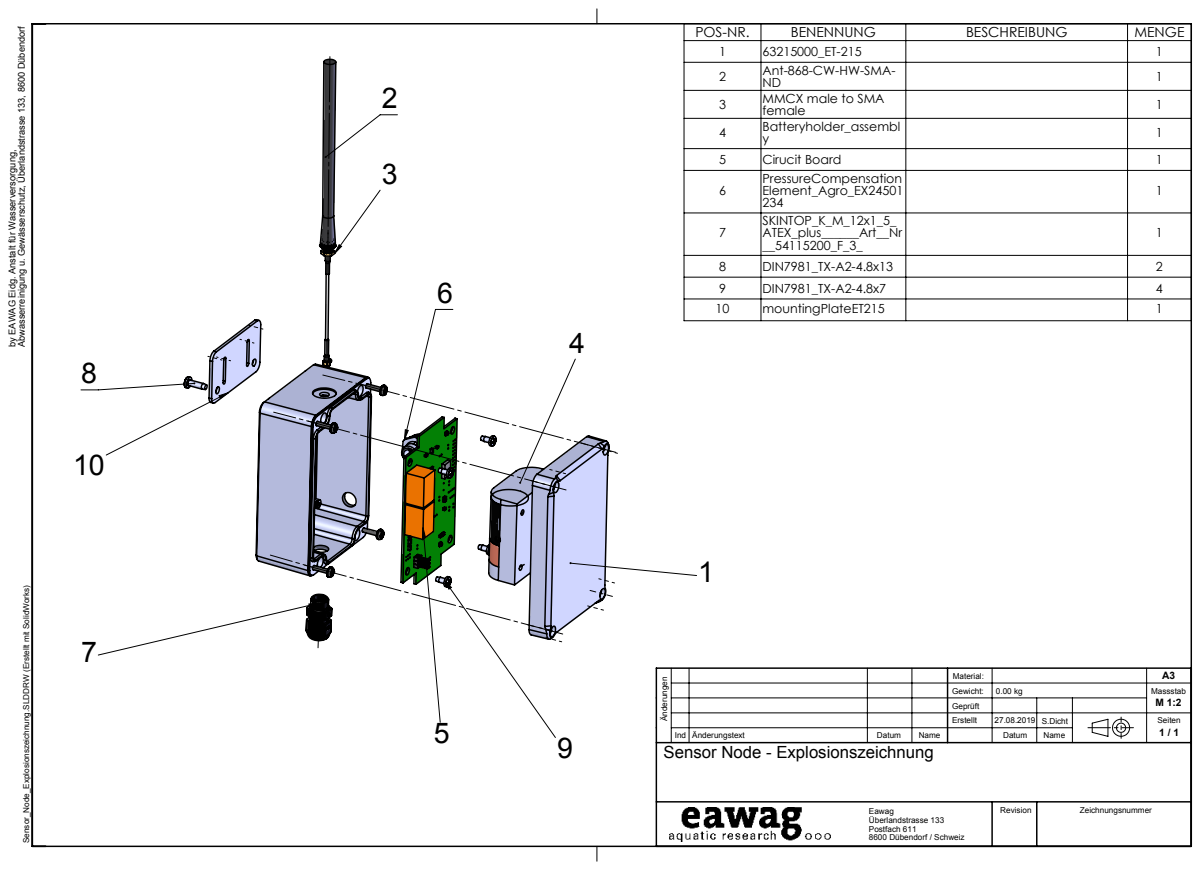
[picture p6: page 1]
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

POS-NR. | 63215000_ET-215 Ant-868-CW-HW-SMA-BENENNUNG | BESCHREIBUNG | MENGE 1 1 2

by EAWAG Eidg. Anstalt für Wasserversorgung, Abwasserreinigung u. Gewässerschutz, Überlandstrasse 133, 8600 Dübendorf Sensor_Node_Explosionszeichnung.SLDDRW (Erstellt mit SolidWorks)

ND MMCX male to SMA | 1 3
female | | 1
4 | Batteryholder_assembl y | | 1

5 | Cirucit Board | | 1
6 | PressureCompensation Element_Agro_EX24501 234 | | 1

7 | SKINTOP_K_M_12x1_5_ ATEX_plus______Art__Nr __54115200_F_3_ | | 1

8 | DIN7981_TX-A2-4.8x13 | | 2
9 | DIN7981_TX-A2-4.8x7 | | 4
10 | mountingPlateET215 | | 1

Sensor Node - Explosionszeichnung

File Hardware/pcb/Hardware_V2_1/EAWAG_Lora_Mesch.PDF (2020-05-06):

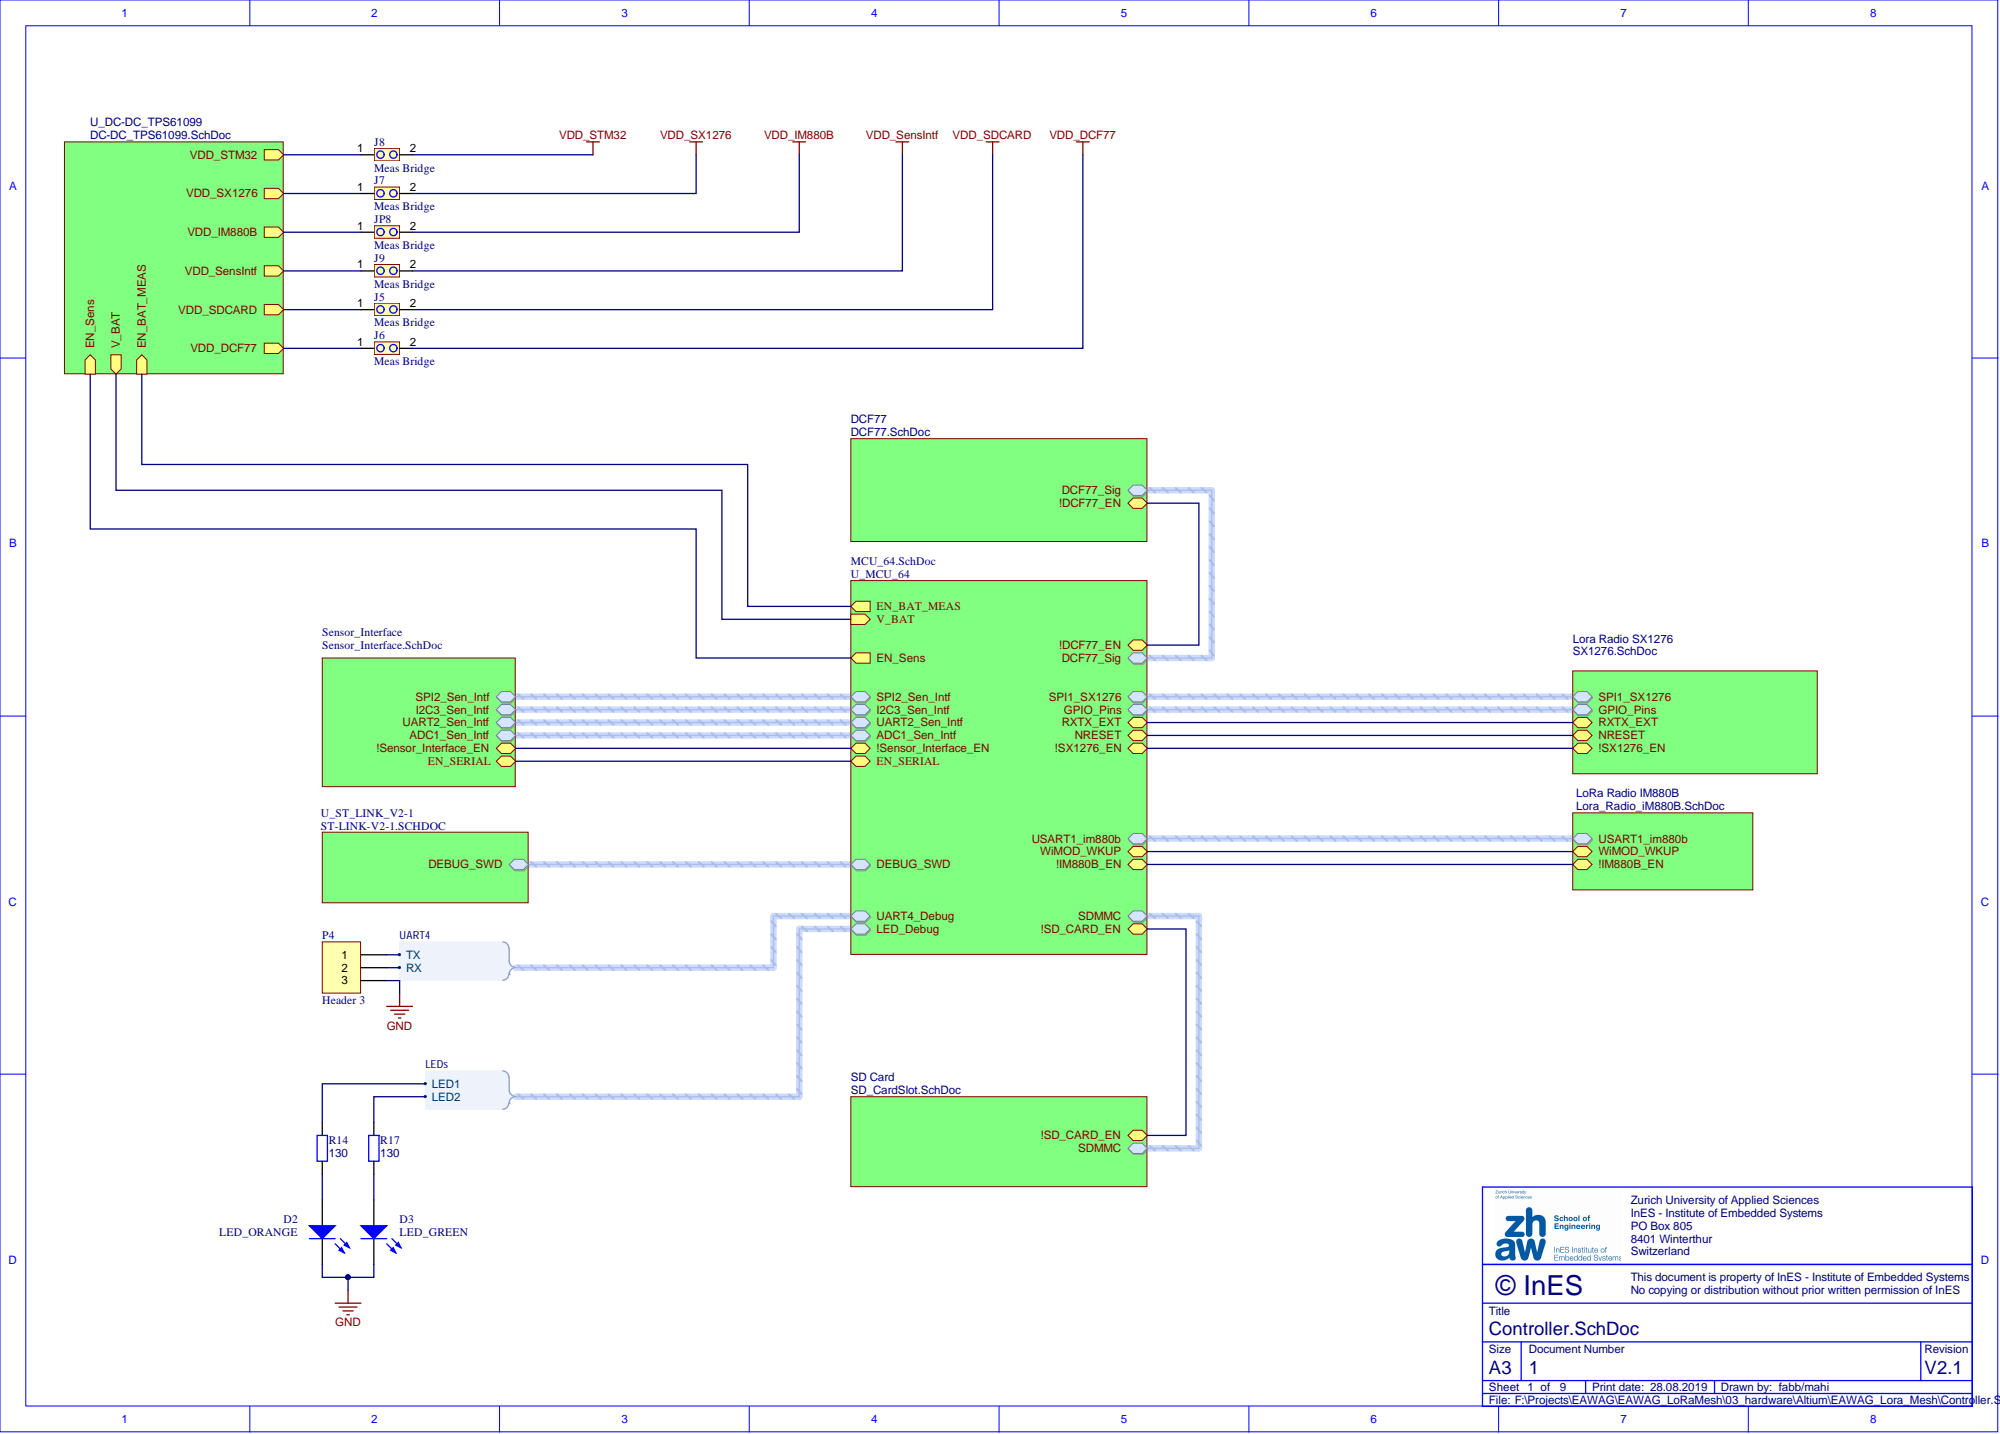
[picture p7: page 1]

Zurich University of Applied Sciences
InES - Institute of Embedded Systems
PO Box 805
8401 Winterthur
Switzerland

This document is property of InES - Institute of Embedded Systems

Size A3 | Document Number | Revision V2.1

Sheet 1 of 9 | Print date: 28.08.2019 | Drawn by: fabb/mahi

F:\Projects\EAWAG\EAWAG_LoRaMesh\03_hardware\Altium\EAWAG_Lora_Mesh\Controller.SchDoc
File:

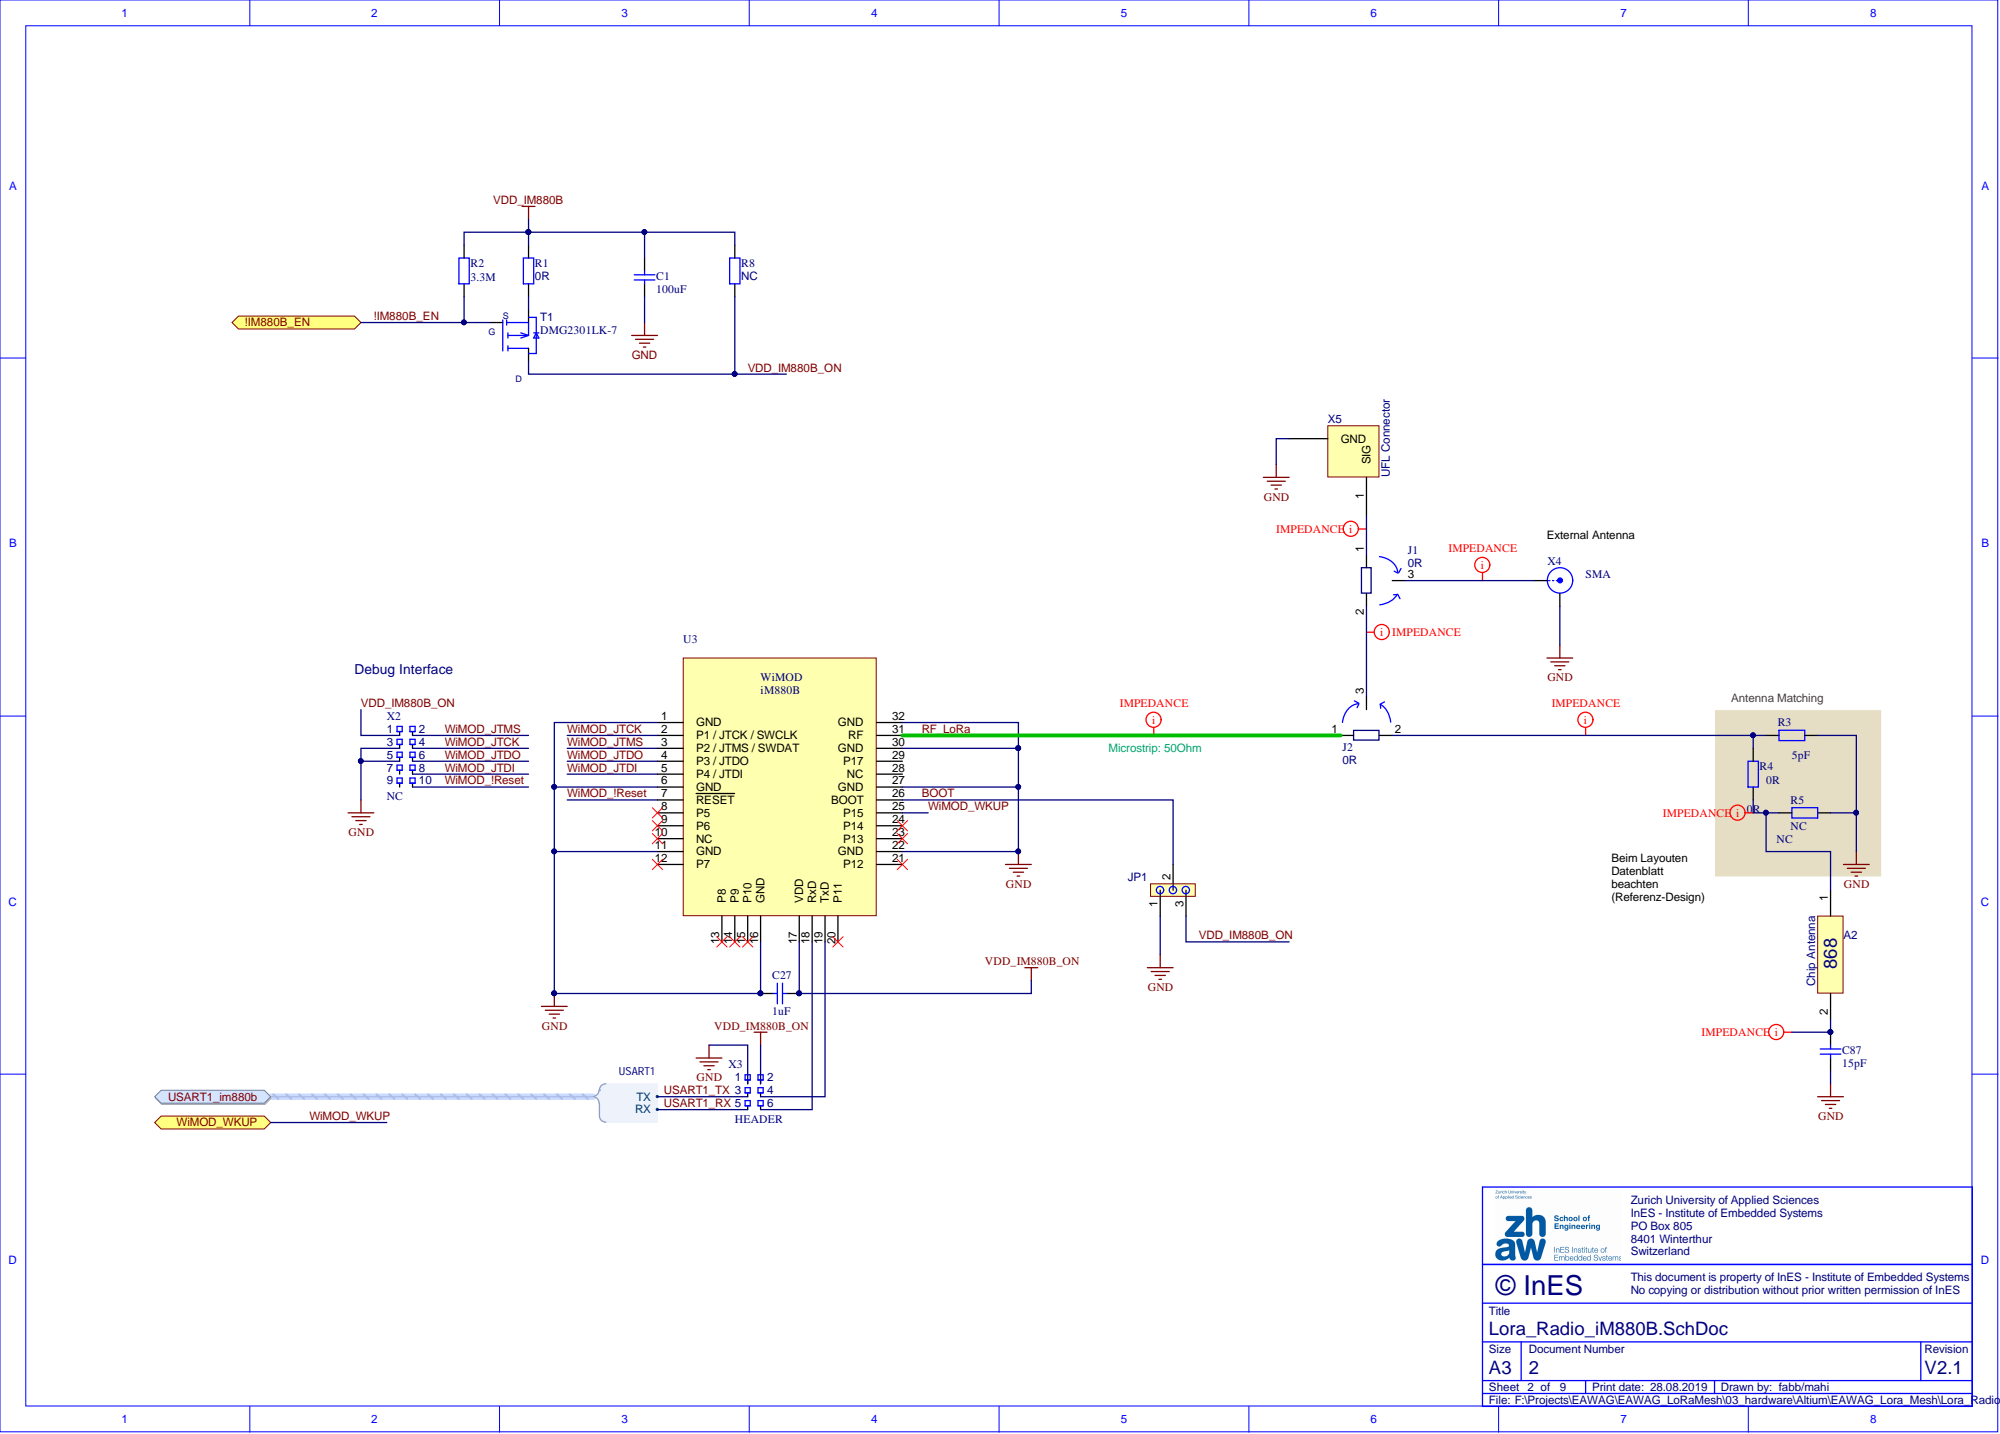
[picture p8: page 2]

P11 20 P12 21 GND 22 P13 23 P14 24 P15 25 BOOT 26 GND 27 NC 28 P17 29 GND 30 RF 31 GND 32

y of Applied Sciences
titute of Embedded Sy
Ins

This document is propert

writ

Lora_Radio_iM880B.SchDoc F:\Projects\EAWAG\EAWAG_LoRaMesh\03_hardware\Altium Siz e | Document Number

Sheet 2 of 9 | Print date: 28.08.2019 | Drawn by : fabb/ mahi

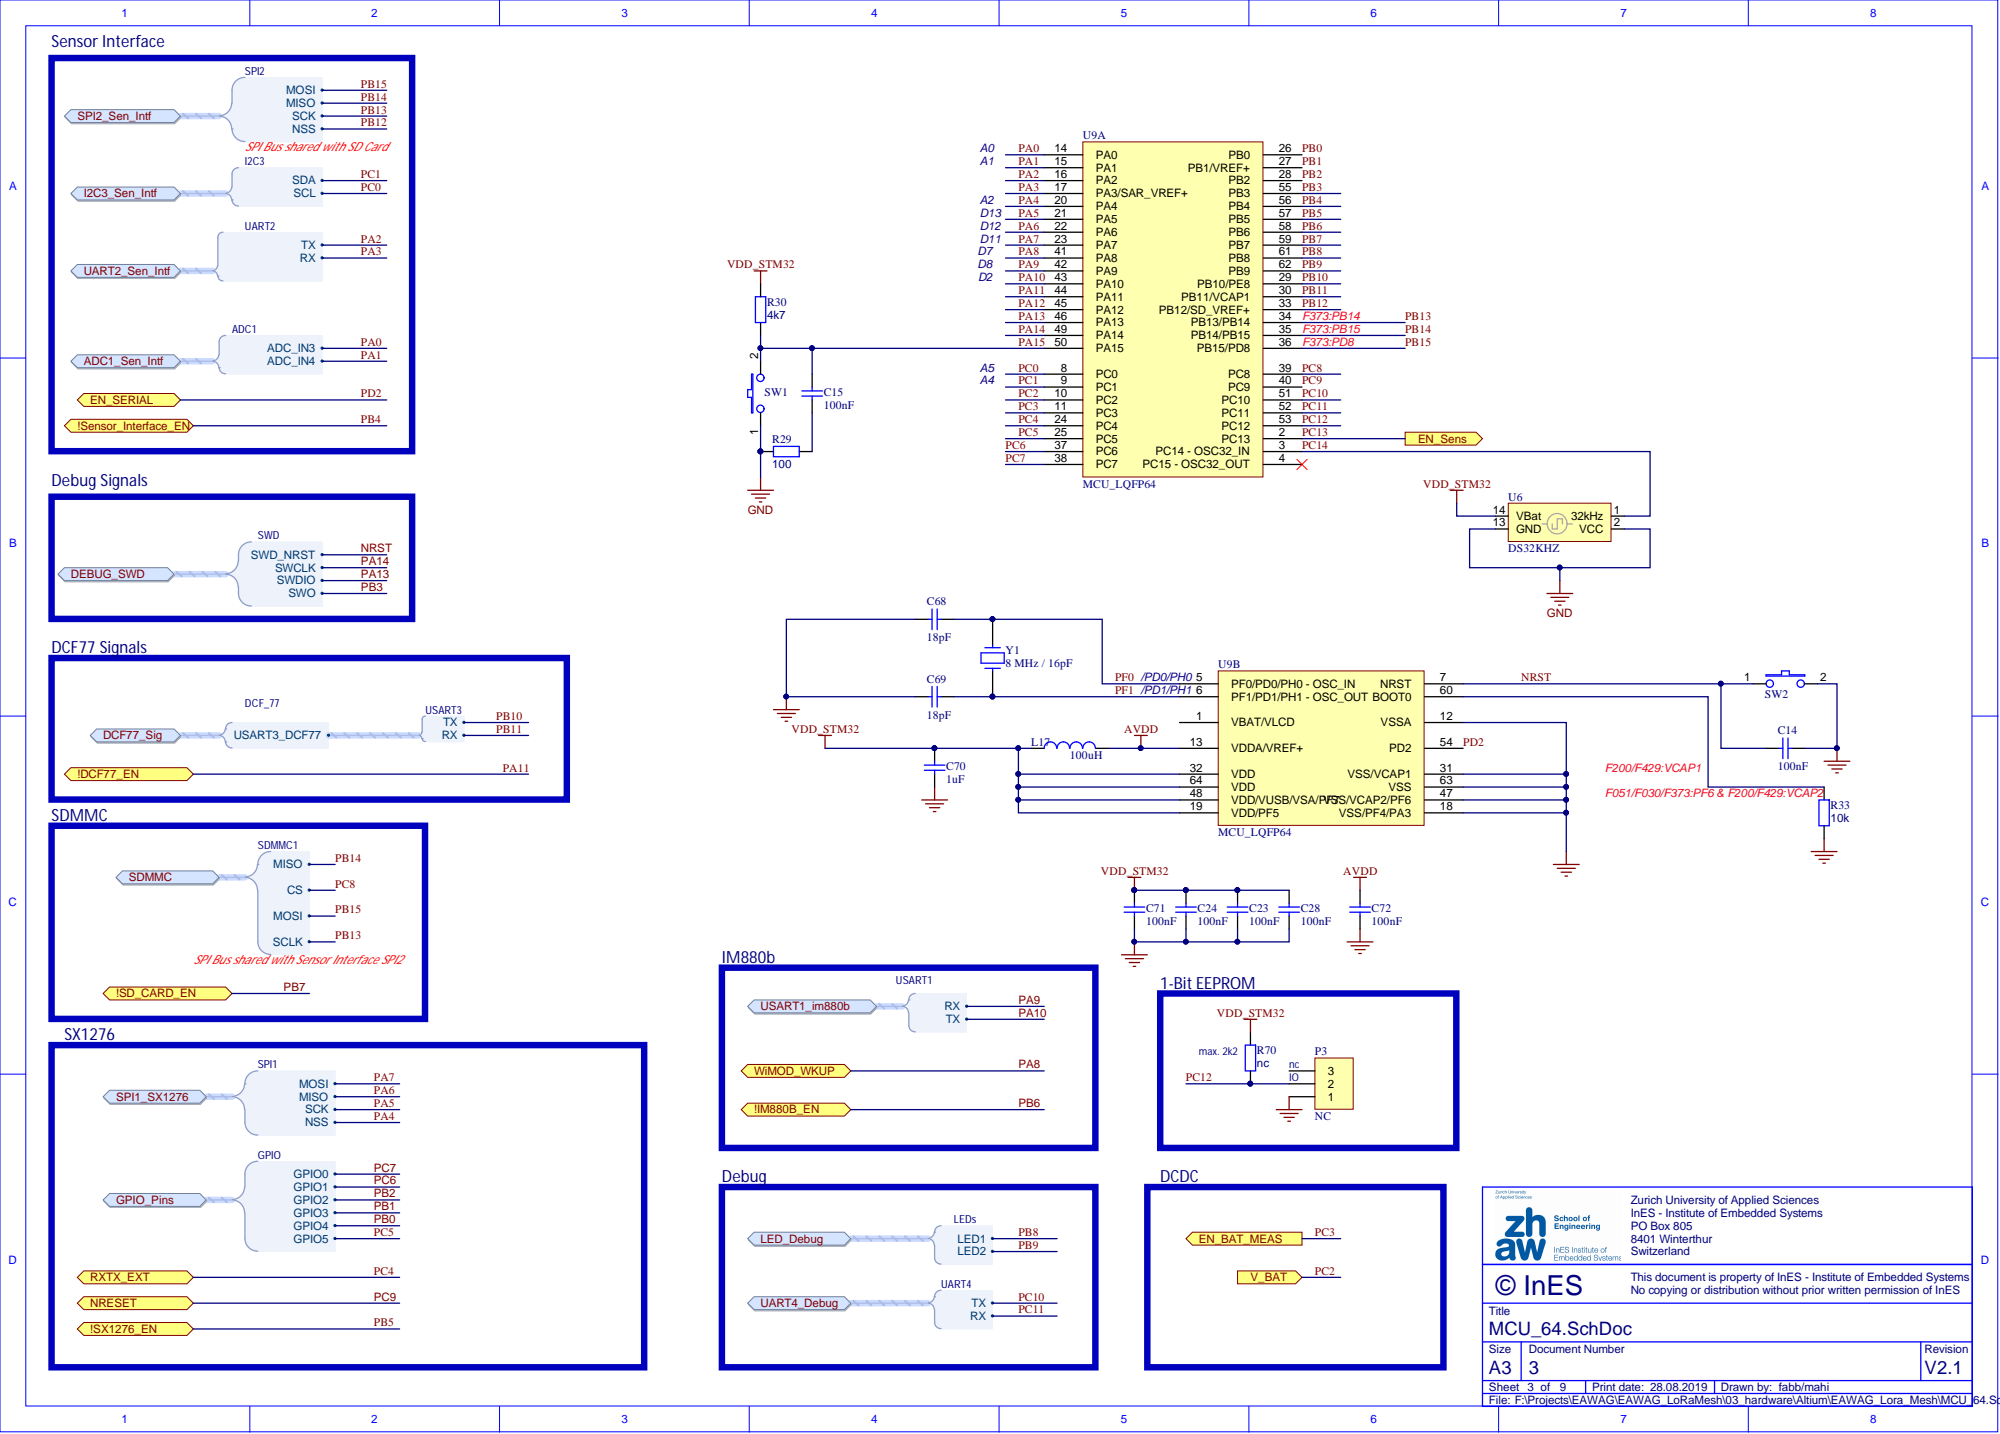
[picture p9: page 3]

SPI Bus shared with SD Card

SPI Bus shared with Sensor Interface SPI2

Zurich University of Applied Sciences
InES - Institute of Embedded Systems
PO Box 805
8401 Winterthur
Switzerland

This document is property of InES - Institute of Embedded Systems

F:\Projects\EAWAG\EAWAG_LoRaMesh\03_hardware\Altium\EAWAG_Lora_Mesh\MCU_64.SchDoc

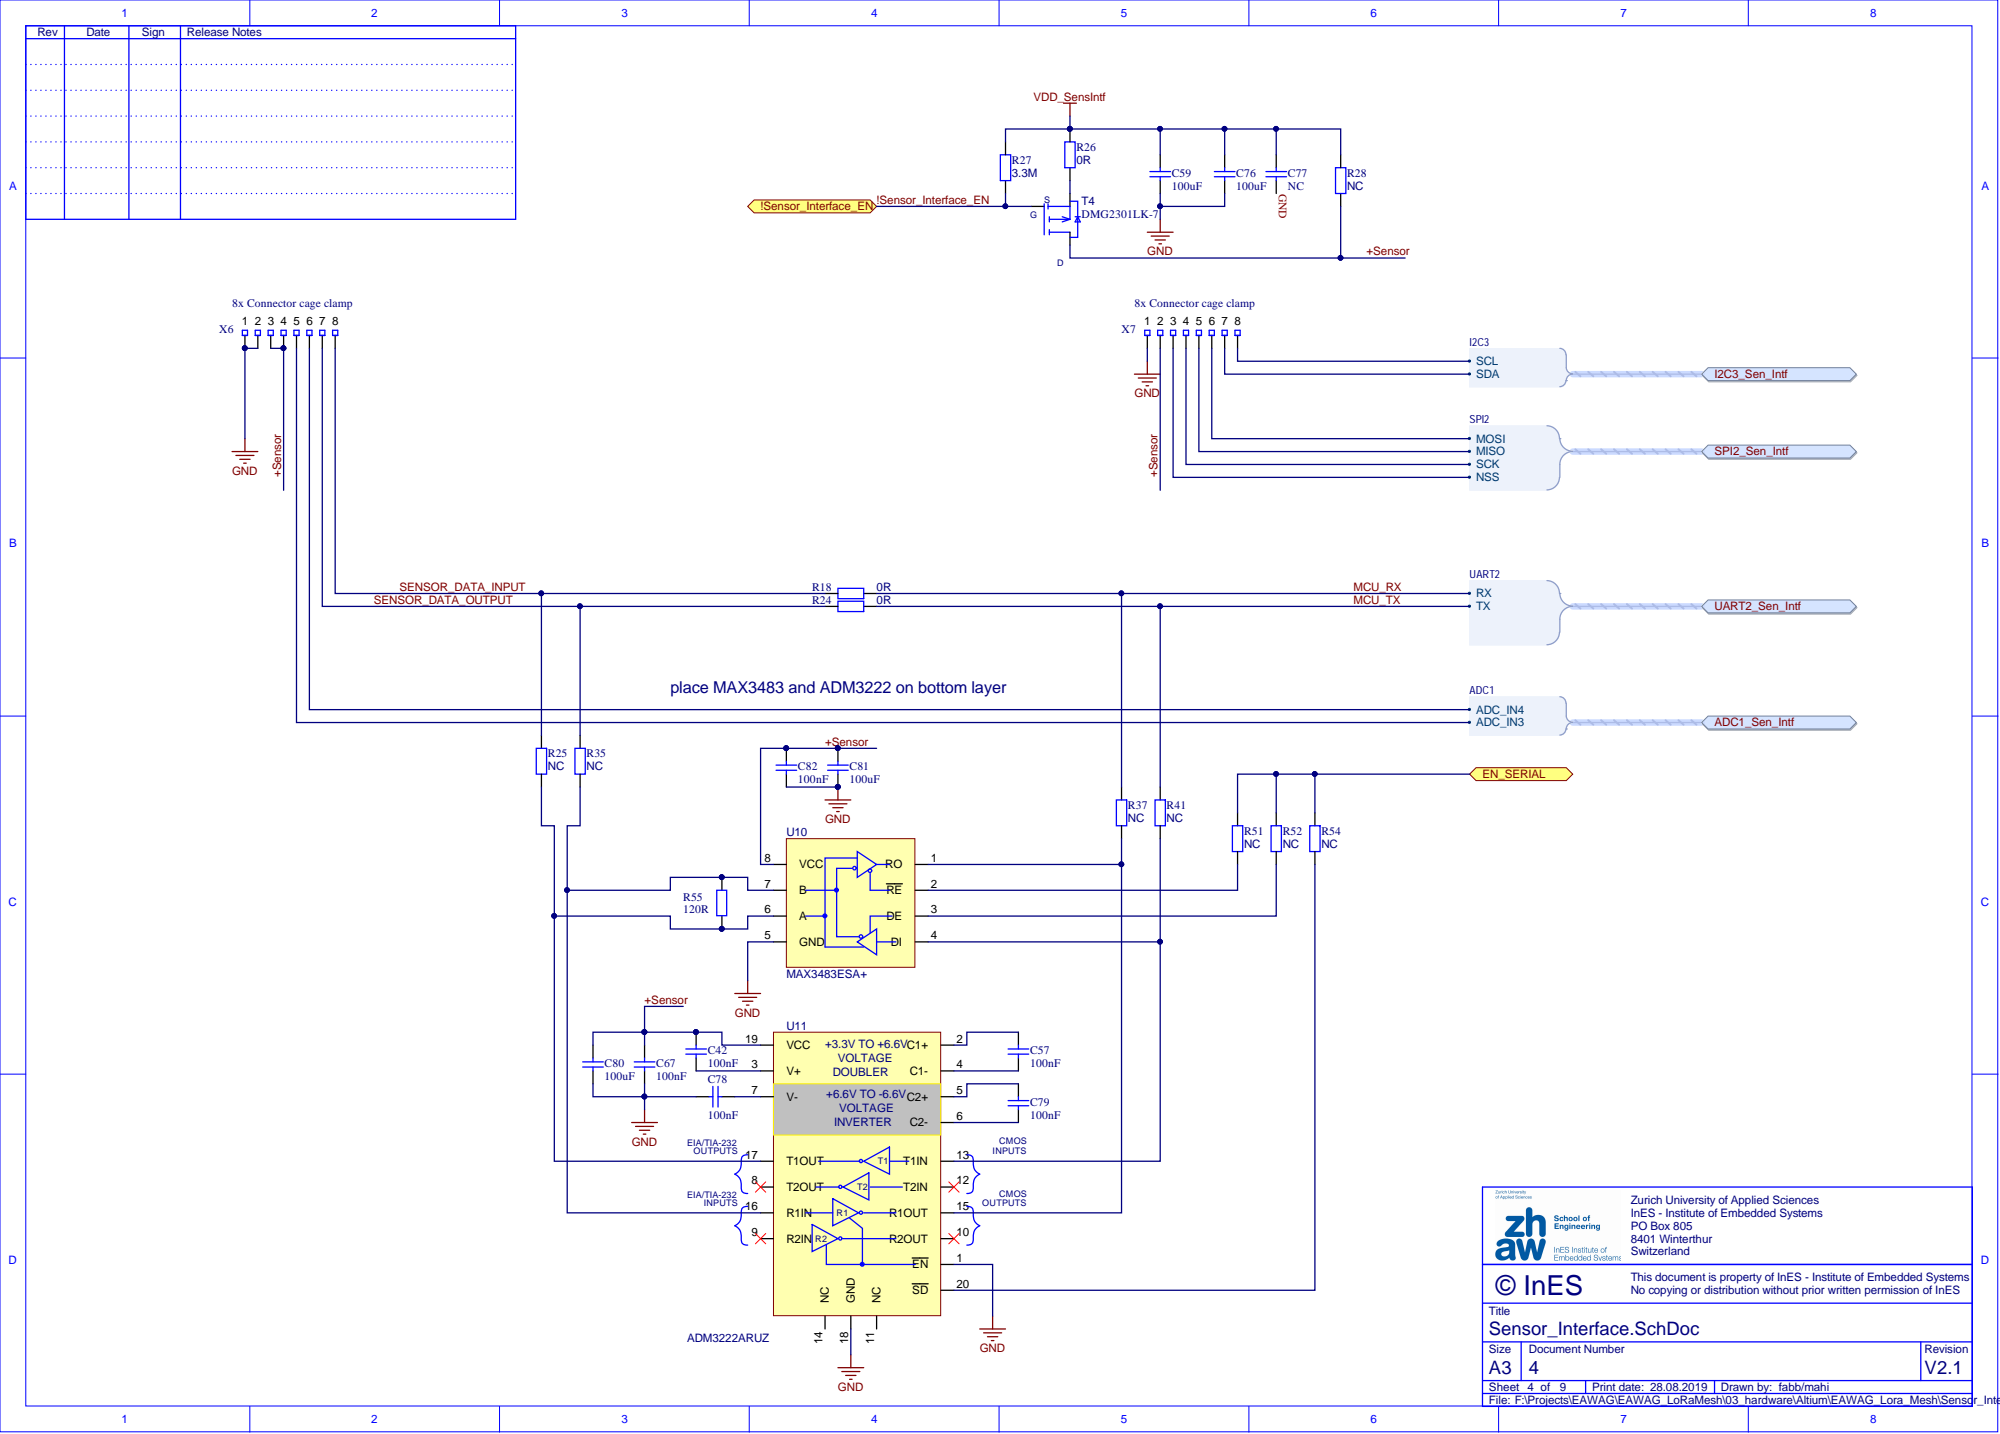
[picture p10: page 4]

place MAX3483 and ADM3222 on bottom layer

+Sensor

Zurich University of Applied Sciences
InES - Institute of Embedded Systems
PO Box 805
8401 Winterthur
Switzerland

This document is property of InES - Institute of Embedded Systems

F:\Projects\EAWAG\EAWAG_LoRaMesh\03_hardware\Altium\EAWAG_Lora_Mesh\Sensor_Interface.SchDoc

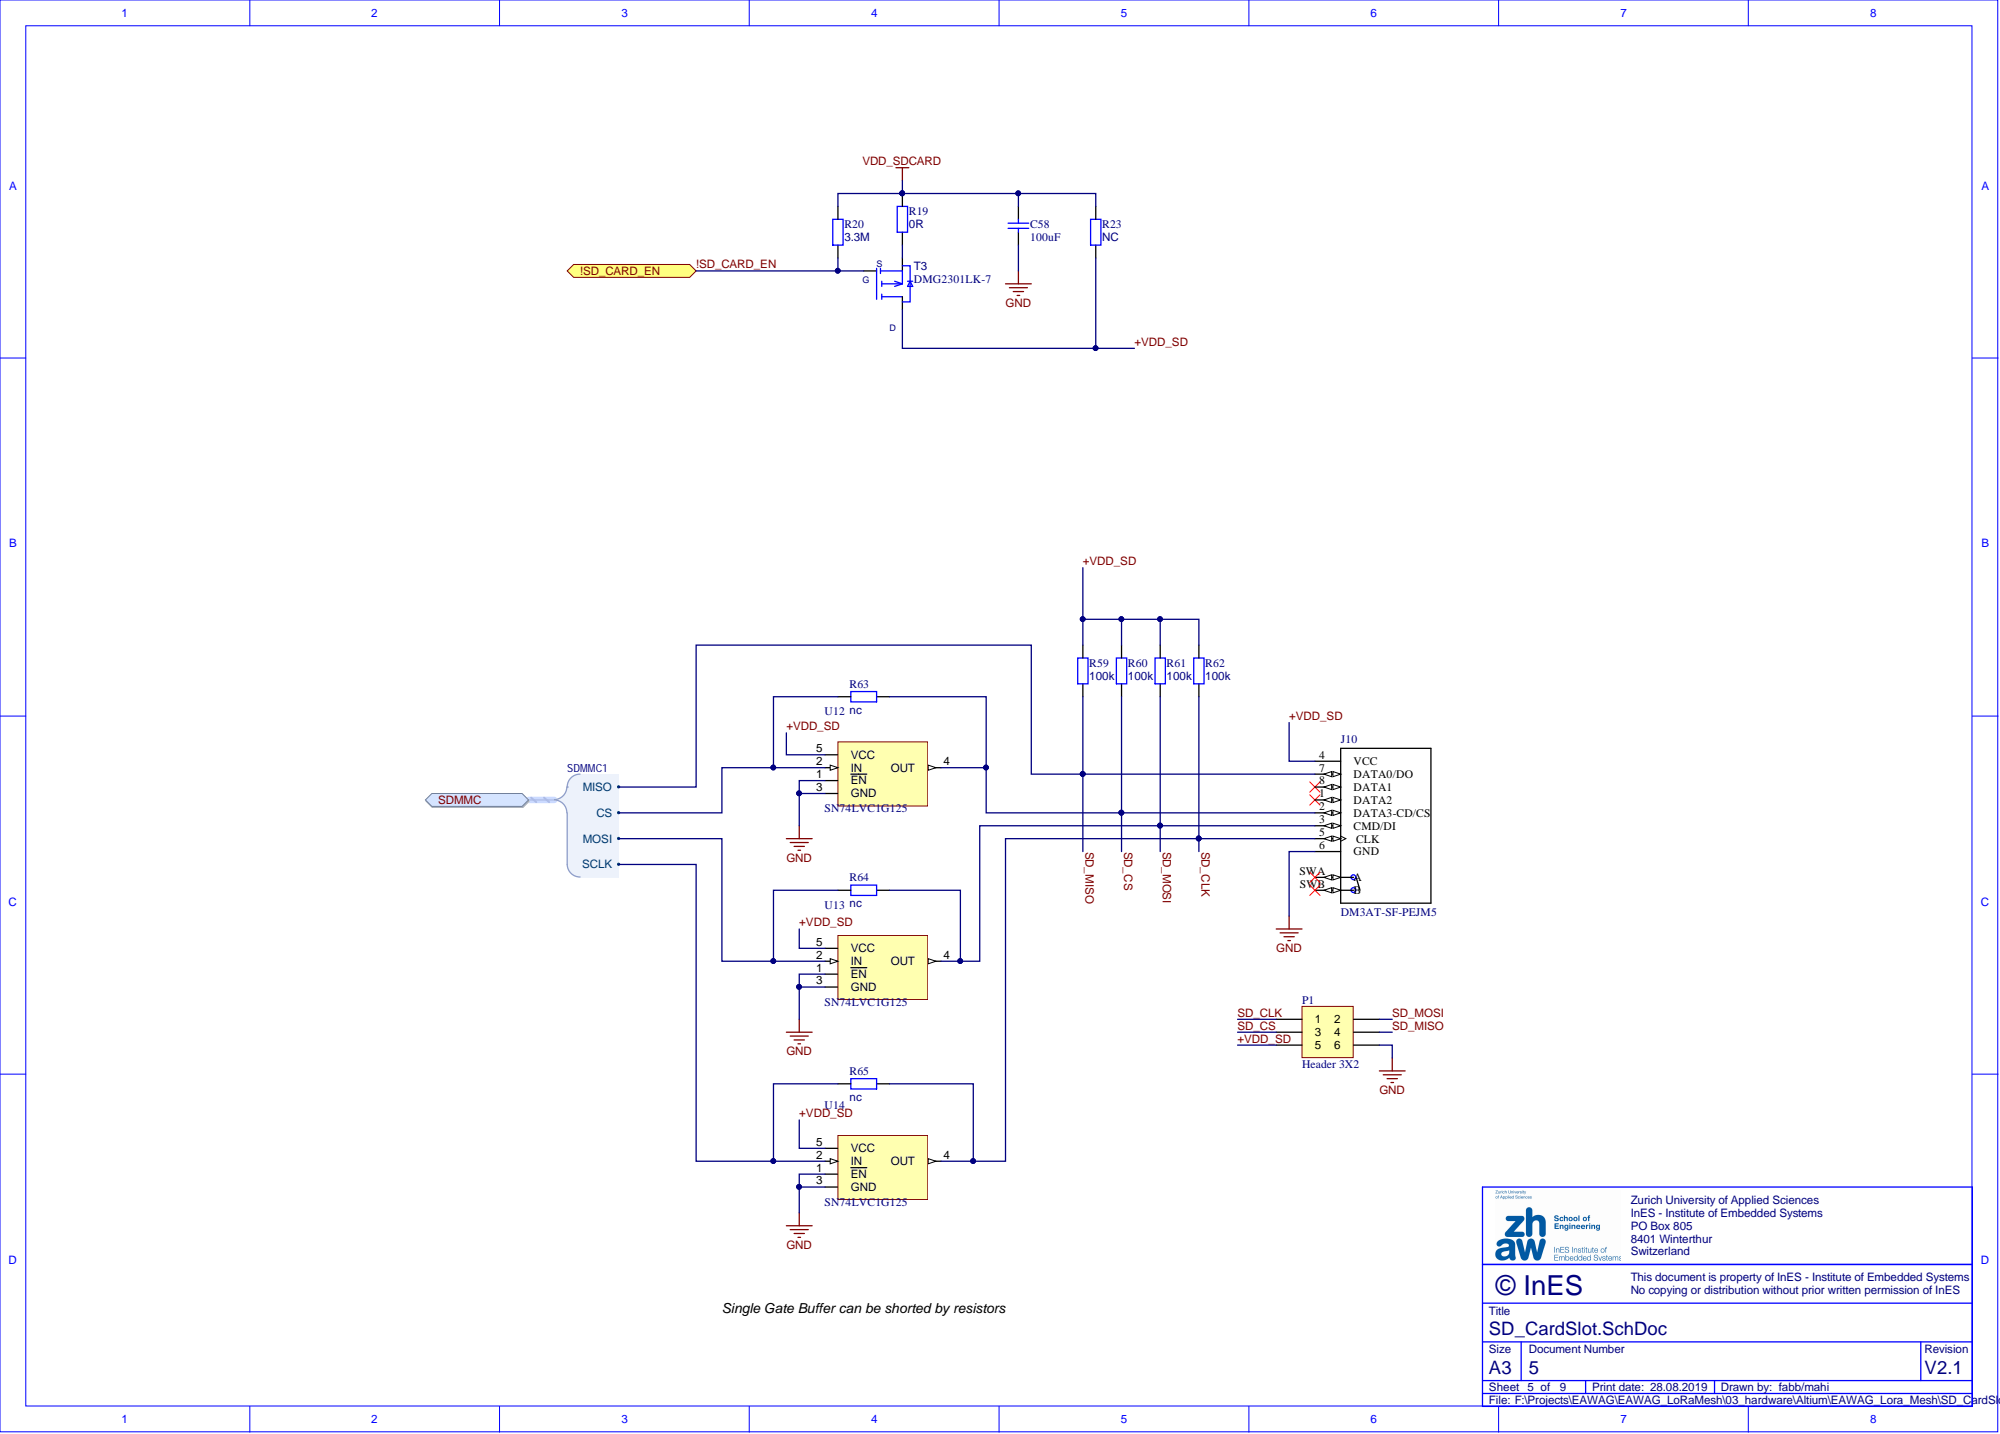
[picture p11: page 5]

GND 6 CMD/DI 3 DATA3-CD/CS 2 DATA2 1 DATA1 8 DATA0/DO 7 VCC 4 CLK 5

Zurich University of Applied Sciences
InES - Institute of Embedded Systems
PO Box 805
8401 Winterthur
Switzerland

This document is property of InES - Institute of Embedded Systems

Single Gate Buffer can be shorted by resistors

F:\Projects\EAWAG\EAWAG_LoRaMesh\03_hardware\Altium\EAWAG_Lora_Mesh\SD_CardSlot.SchDoc

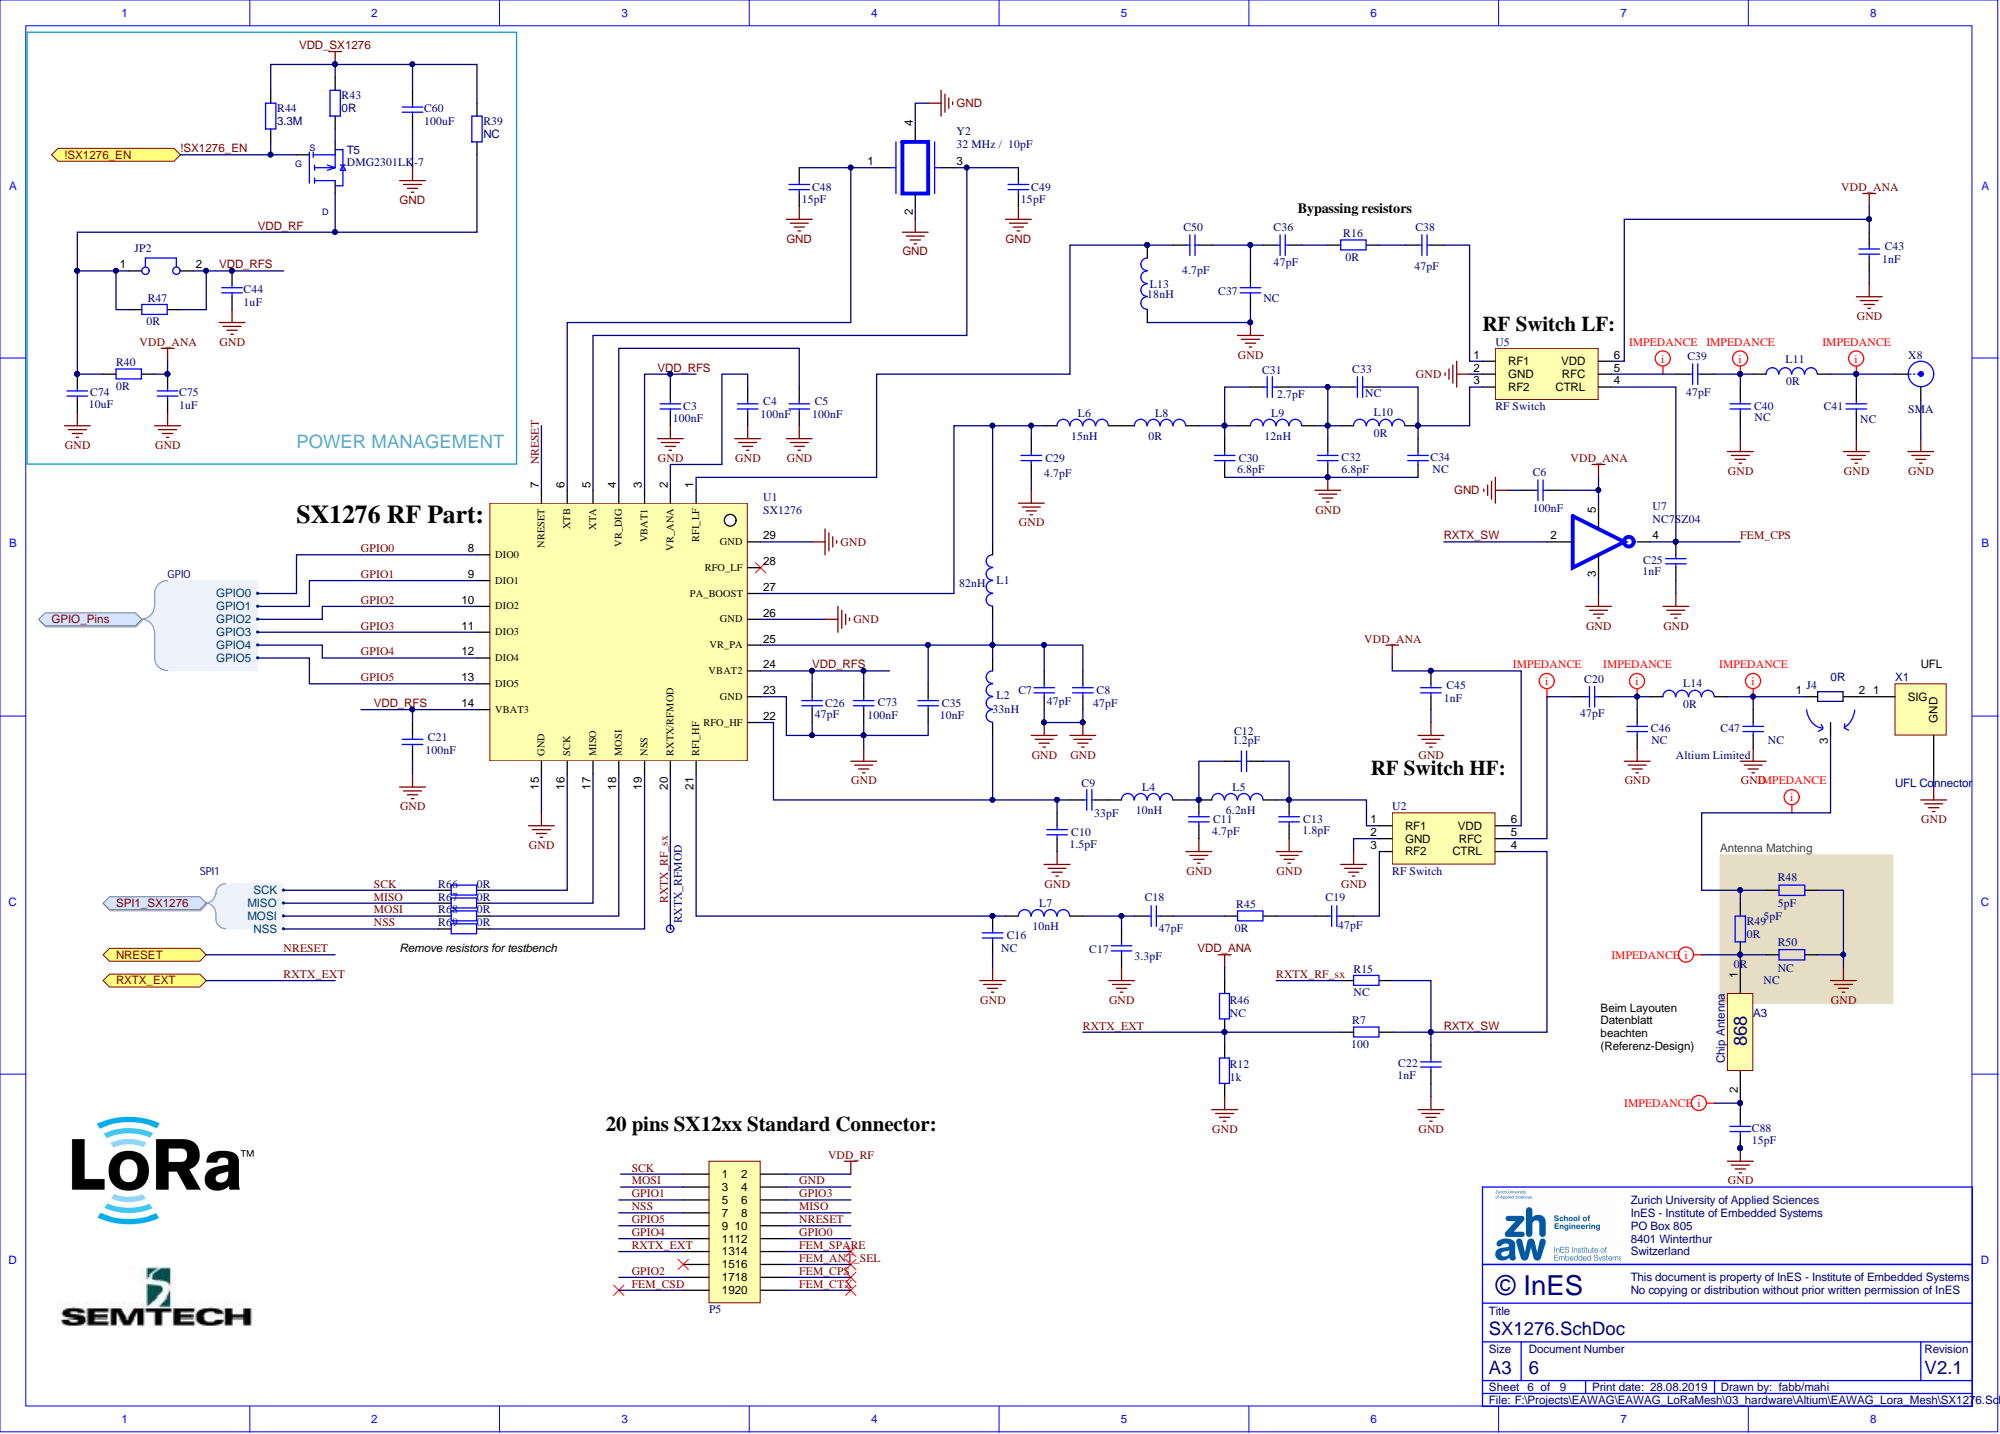
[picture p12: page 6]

GPIO1 | DIO1 9

DIO2 10

Remove resistors for testbench

Zurich University of Applied Sciences
InES - Institute of Embedded Systems
PO Box 805
8401 Winterthur
Switzerland

This document is property of InES - Institute of Embedded Systems

F:\Projects\EAWAG\EAWAG_LoRaMesh\03_hardware\Altium\EAWAG_Lora_Mesh\SX1276.SchDoc

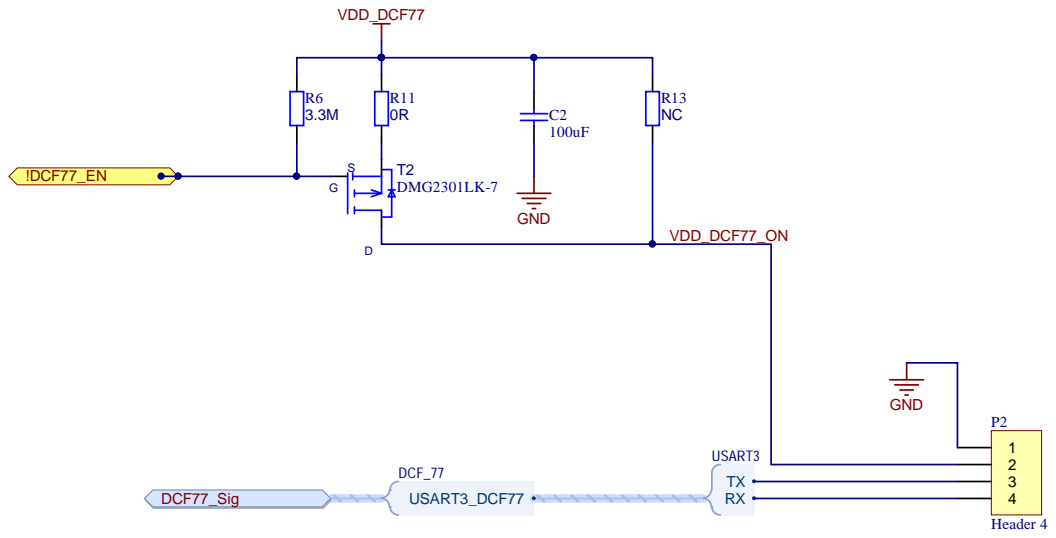
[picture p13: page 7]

Zurich University of Applied Sciences
InES - Institute of Embedded Systems
PO Box 805
8401 Winterthur
Switzerland

This document is property of InES - Institute of Embedded Systems

F:\Projects\EAWAG\EAWAG_LoRaMesh\03_hardware\Altium\EAWAG_Lora_Mesh\DCF77.SchDoc


y of Applied Sciences
titute of Embedded Sy
Ins

This document is propert

writ

DC-DC_TPS61099.SchDoc F:\Projects\EAWAG\EAWAG_LoRaMesh\03_hardware\Altium Siz e | Document Number

Sheet 8 of 9 | Print date: 28.08.2019 | Drawn by : s cag


Zurich University of Applied Sciences
InES - Institute of Embedded Systems
PO Box 805
8401 Winterthur
Switzerland

This document is property of InES - Institute of Embedded Systems

F:\Projects\EAWAG\EAWAG_LoRaMesh\03_hardware\Altium\EAWAG_Lora_Mesh\ST-LINK-V2-1.SCHDOC
